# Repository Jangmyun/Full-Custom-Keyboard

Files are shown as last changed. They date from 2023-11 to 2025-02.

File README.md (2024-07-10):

# Full-Custom-Keyboard

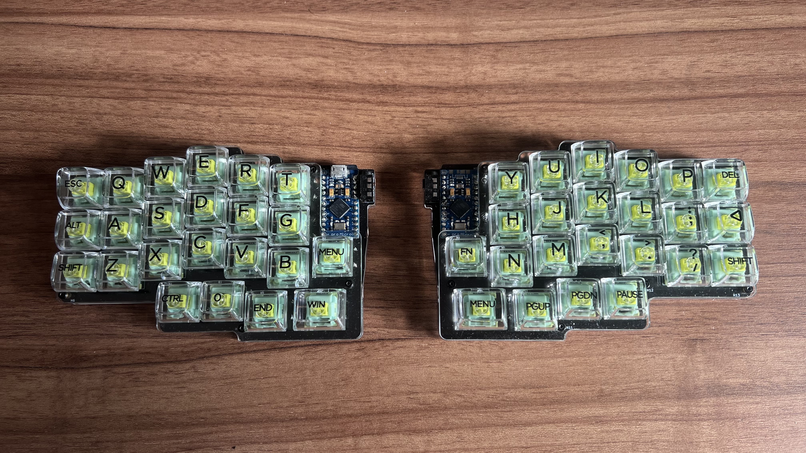
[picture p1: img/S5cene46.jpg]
s5cene


##### 목표: 아두이노 프로 마이크로 또는 rp2040-zero 보드를 사용하여 스플릿 키보드 제작

###### 저는 전자 비전공자이고, 전기 전자 아무것도 몰라도 무리없이 키보드 제작이 가능했습니다.<br>이 글은 구글링해서 얻은 자료들을 제작 순서에 맞게 짜깁기 한 내용에 불과합니다.

<br><br>

## 순서:

1. #### 레이아웃 설계

2. #### 회로도 설계

3. #### pcb 설계

4. #### 보강판, 상판 설계

5. #### pcb, 부품 주문

6. #### 납땜, qmk 펌웨어 플래시

7. #### 완성

<br><br>

1. ## 레이아웃 설계

#### 키보드 레이아웃 == 키보드 배열

##### 보통 키보드 레이아웃은 키보드 배열을 말하는데, 어떤 배열의 키보드를 만들지 정해야 회로도나 pcb를 설계할 때 고민할 일이 없으니 만들어 놓고 시작하는 것이 좋습니다.<br>키보드 레이아웃은 [keyboard-layout-editor](http://www.keyboard-layout-editor.com/) 에서 만들 수 있습니다.<br>GitHub 계정이 있다면 만든 레이아웃을 저장할 수도 있습니다. JSON 파일로 저장해도 됩니다.

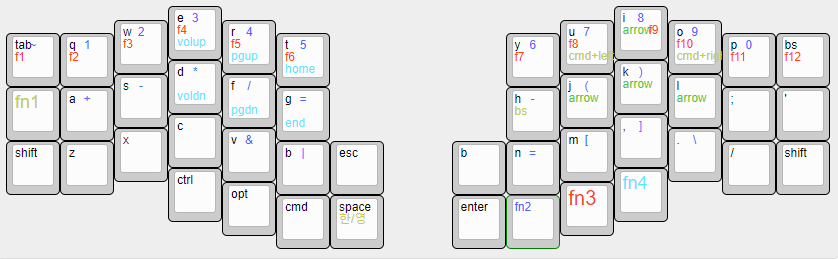
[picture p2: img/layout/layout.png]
layout


##### 저는 위 배열로 만들겠습니다. fn키를 누르면 나오는 키는 qmk 펌웨어를 사용해서 원하는 대로 어떤 것이든 지정할 수 있으니 나중에 편한대로 커스텀 해도 됩니다.

<br><br><br>

2. ## 회로도 설계

##### 회로도와 PCB는 [KiCad](https://www.kicad.org/) 라는 프로그램을 사용해서 설계할 것입니다. 버전은 7.0 이상의 stable 버전을 기준으로 설명하겠습니다.

<br>

### 회로도 설계전에 알아야 할 내용

#### [키보드 매트릭스 원리 이해하기](https://m.blog.naver.com/kdahaam/221495967863)에 잘 정리되어 있습니다.

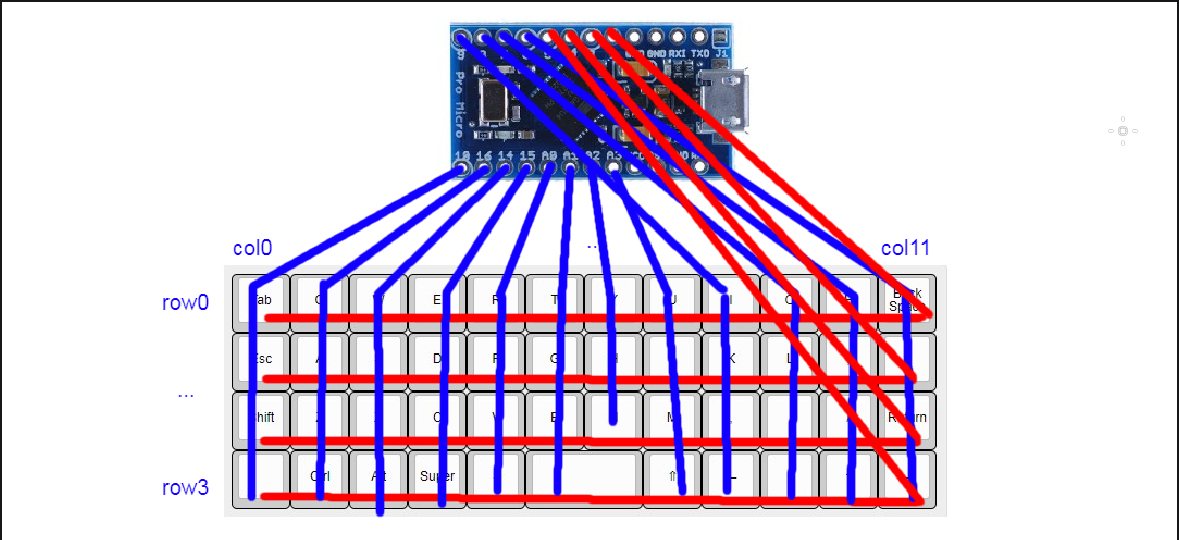
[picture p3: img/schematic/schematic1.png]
keyboard matrix


##### 

##### 적게는 40키, 많게는 100키가 넘어가는 키보드의 모든 스위치를 하나하나 컨트롤러에 연결하기에 컨트롤러의 핀 개수가 모자르게 됩니다. <br>때문에 행과 열로 스위치를 묶어서 연결하고 각 행과 열을 컨트롤러에 연결하면 훨씬 적은 핀으로 다수의 스위치를 인식할 수 있게 됩니다.<br><br>이렇게 되면 스위치를 하나만 눌렀을 때는 잘 작동하지만 여러 스위치를 동시에 눌렀을 때 눌리지 않은 키까지 인식하는 경우가 생깁니다. 이럴 때 사용하는 것이 `다이오드` 입니다. <br><br>다이오드는 전기를 한 방향으로만 흐르게 만드는 데, 이게 누르지 않은 스위치가 눌리는 현상을 막아줍니다. 잘 이해가 안된다면 `스위치 하나당 다이오드 하나가 필요하다` 정도로 생각하면 되겠습니다. 저는 46개의 스위치를 사용하기 때문에 다이오드 46개가 필요하겠네요.

<br><br>

### 회로도를 설계전에 필요한 파일 설치

#### KiCad를 실행합니다.

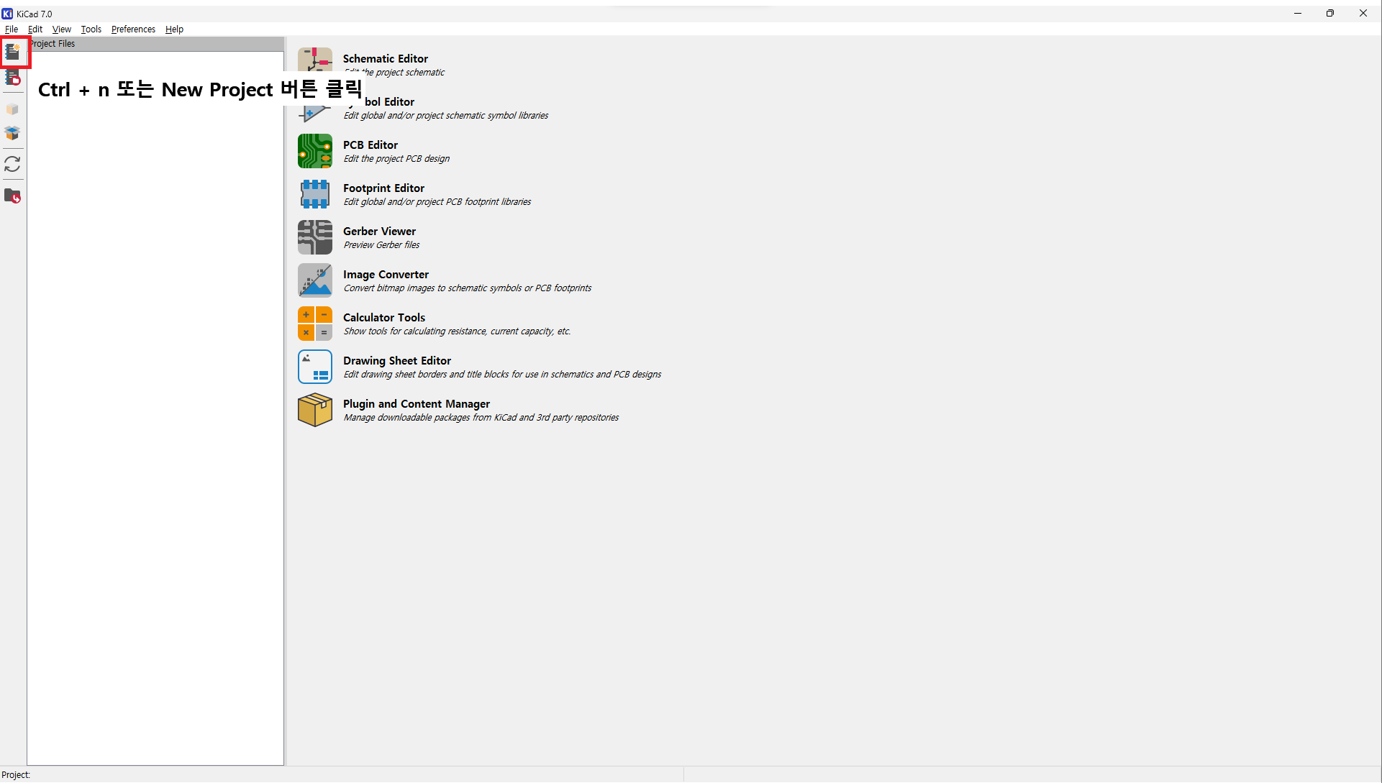
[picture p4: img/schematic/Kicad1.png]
Kicad1


##### `Ctrl + n` 또는 New Project를 눌러 새로운 프로젝트를 생성합니다. 프로젝트를 생성했을 때 `프로젝트이름.kicad_pcb`와 `프로젝트이름.kicad_sch`파일을 확인하면 됩니다.

#### Footprint와 Symbol 라이브러리 다운로드

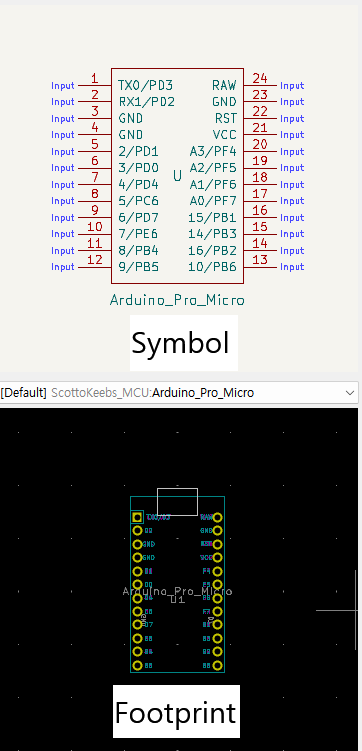
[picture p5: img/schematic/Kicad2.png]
Symbol and Footprint


##### Symbol은 우리가 키보드에 사용할 부품의 회로도 그림이고, Footprint는 pcb 설계할 때 사용할 부품의 실제 그림이라고 생각하면 되겠습니다.<br>우리가 사용할 부품을 잘 정리해놓은 [scottoKicad](https://github.com/joe-scotto/scottokeebs/tree/main/Extras/ScottoKicad)가 있습니다. [DownGit](https://minhaskamal.github.io/DownGit/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)사이트에서 바로 다운로드 할 수 있습니다.<br>라이브러리 적용 방법은 [KiCad 라이브러리 적용방법](https://github.com/Jangmyun/Full-Custom-Keyboard/tree/main/kicadLibrary)에 정리해두었습니다.

<br><br>

### 본격적으로 회로도를 그려봅시다.

##### 프로젝트 폴더를 열고 `kicad_sch`파일을 열어줍니다.

<p width="100%">
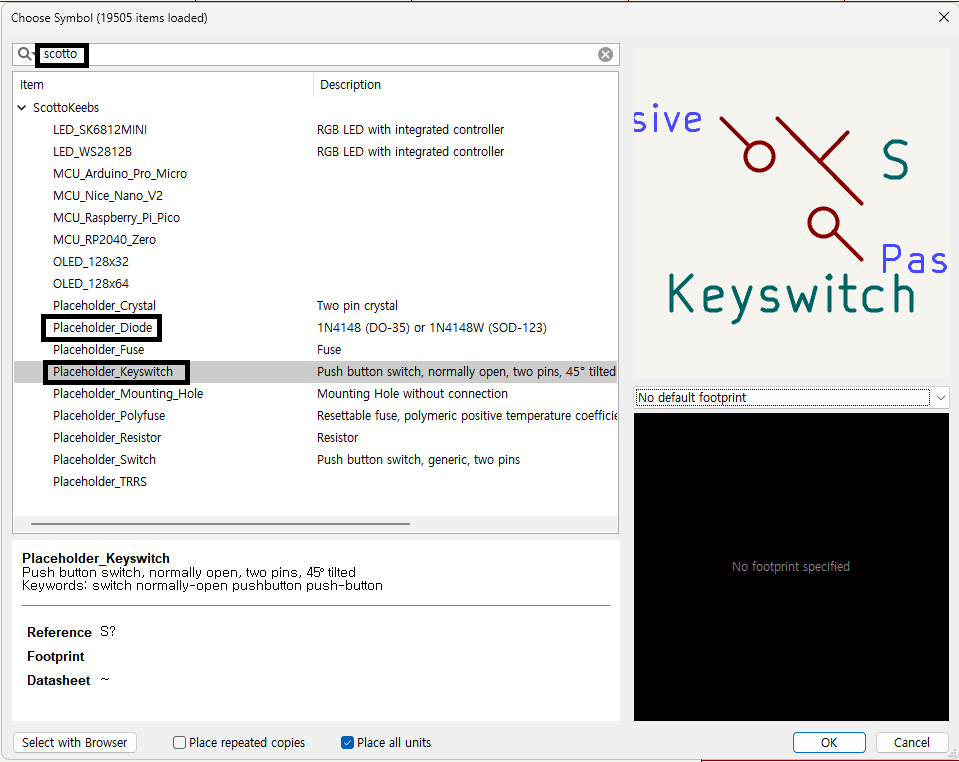
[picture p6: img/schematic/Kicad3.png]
  
</p>

##### 단축키 `A`를 눌러 스위치와 다이오드 심볼을 추가해주겠습니다. `scottokeebs`로 검색하면 앞서 적용한 심볼 라이브러리를 찾을 수 있습니다.

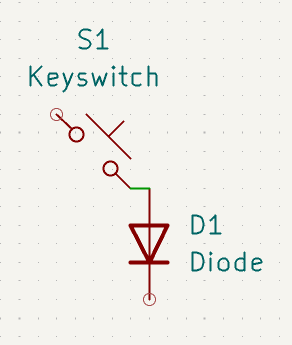
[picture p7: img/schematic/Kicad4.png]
keyswitch and diode


##### 추가한 스위치와 다이오드를 옮겨서 위와같이 만들어줍니다. 스위치와 다이오드 하나가 세트입니다.<br>이제 앞에서 만든 레이아웃대로 스위치와 다이오드를 배치하겠습니다.<br>스위치와 다이오드를 드래그하고 복사하면 됩니다. 일정한 간격으로 배치해야 와이어를 연결할 때 편리합니다.

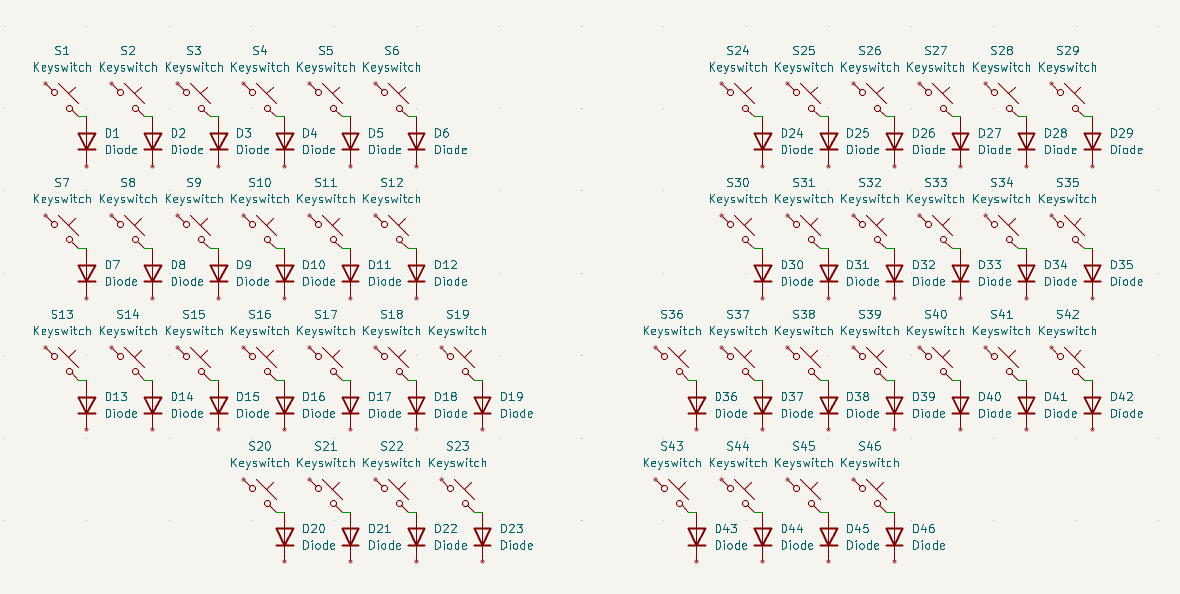
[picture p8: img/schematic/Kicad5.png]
schematic


##### 어지럽긴 하지만 이런식으로 배치가 됩니다. 저는 스플릿 키보드라서 좌,우 각각 떨어뜨려놨습니다.<br><br>이제 단축키 `W`로 각 행과 열을 연결해주겠습니다.

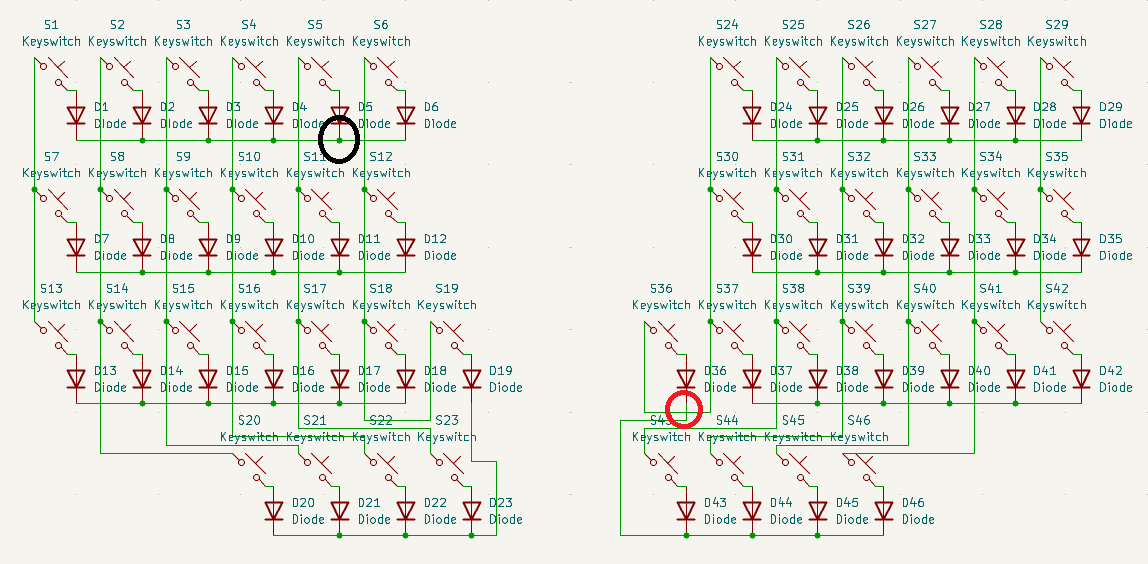
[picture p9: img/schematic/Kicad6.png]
schematic wiring


##### 이런 구조가 되는데, 연결할 때 검은색 원 안의 초록색 점은 서로 연결되었다는 뜻입니다. 연결되지 않은 선 끼리는 빨간색 원처럼 아무것도 표시되지 않습니다. 와이어 교차할 때 주의해야 합니다.

##### 다음은 각 행과 열에 라벨을 붙여줘야 합니다. 같은 이름의 라벨은 PCB 설계 단계에서 서로 연결됩니다.<br>`Ctrl + L`또는 회로도 편집기 우측의 `Global Label`을 선택하고 이름을 정해주면 됩니다.

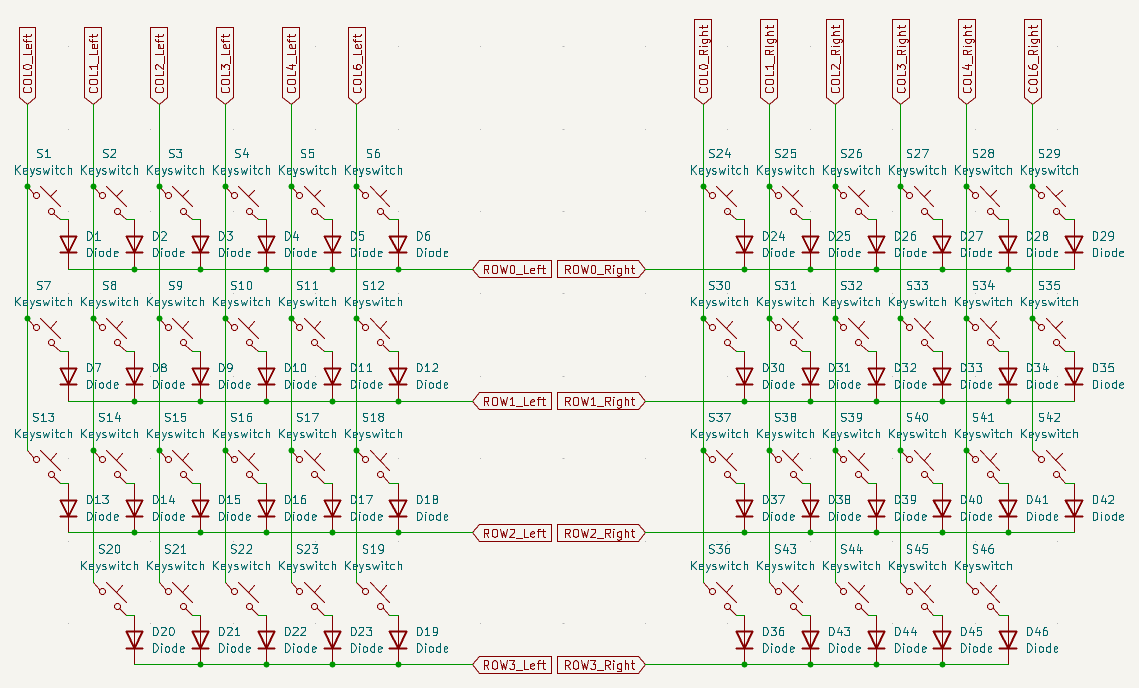
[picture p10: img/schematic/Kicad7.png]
Global Label


##### 라벨을 보기쉽게 만드려고 회로도를 조금 수정했습니다. 저는 스플릿 키보드를 만들거라 왼쪽 오른쪽의 라벨 이름을 구분해줬습니다. 보통 행열 라벨은 `col`과 `row`로 작명합니다.

##### 이제 MCU를 회로도에 추가합니다. 스플릿 키보드라서 두개 추가해줍니다. 저는 rp2040-zero를 사용하겠습니다. 단축키 `A`를 누르고 rp2040-zero를 추가합니다.

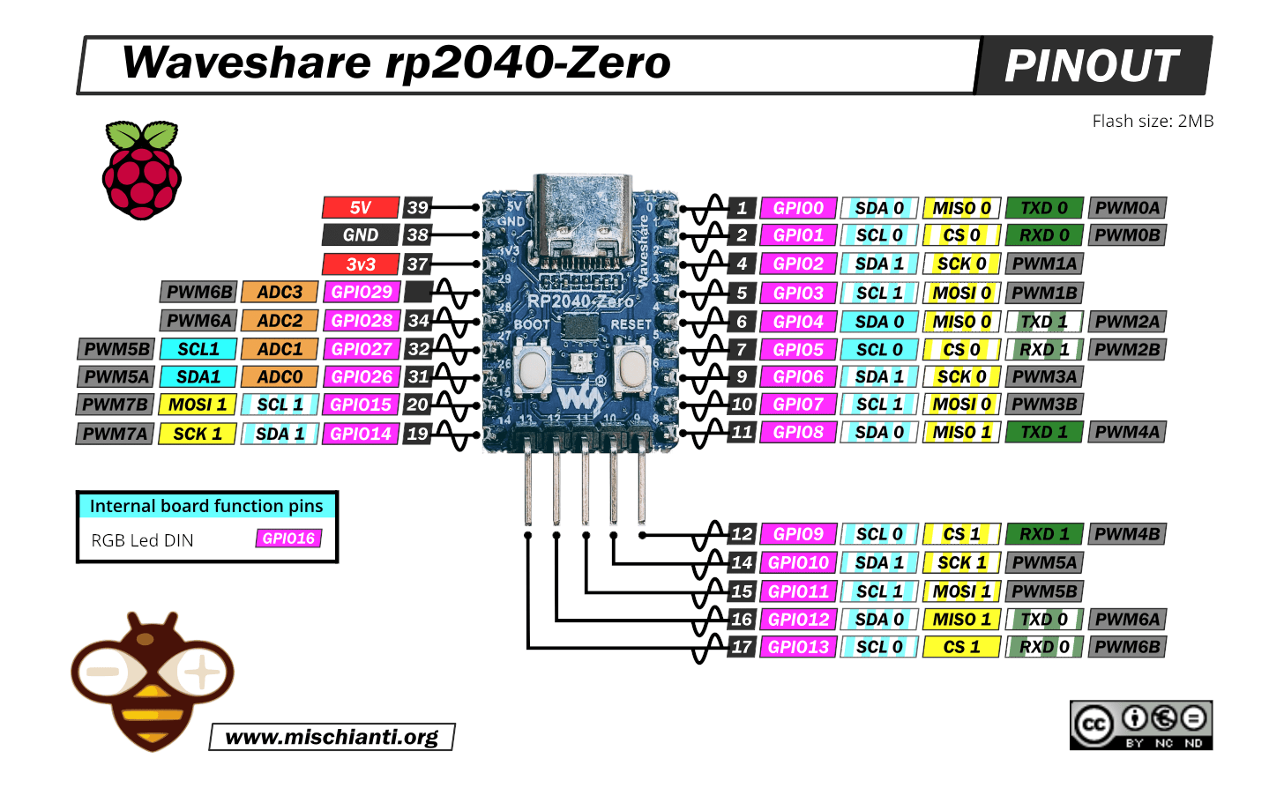
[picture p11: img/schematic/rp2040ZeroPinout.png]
rp2040-zero-pinout (https://mischianti.org/waveshare-rp2040-zero-high-resolution-pinout-and-specs/)


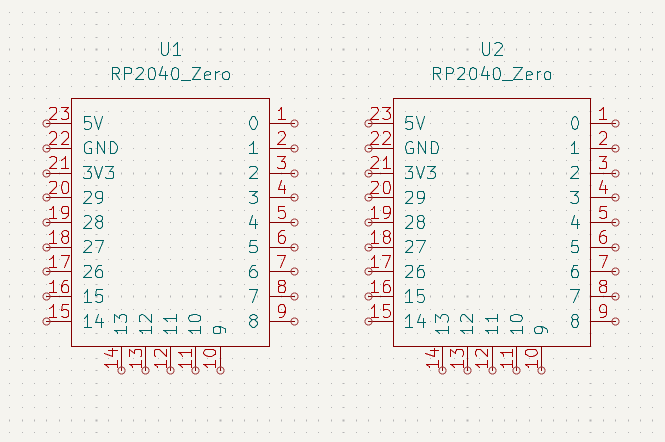
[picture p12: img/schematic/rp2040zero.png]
rp2040-zero


##### 총 23개의 핀이 있는데 그중에서 `3V3`,`GND`,`5V`외에는 자유롭게 행열을 연결할 수 있습니다. 다만 스플릿 키보드를 만들 때는 좌우 컨트롤러의 시리얼 통신을 위해 `GPIO0`, `GPIO1` 핀을 비워주겠습니다.

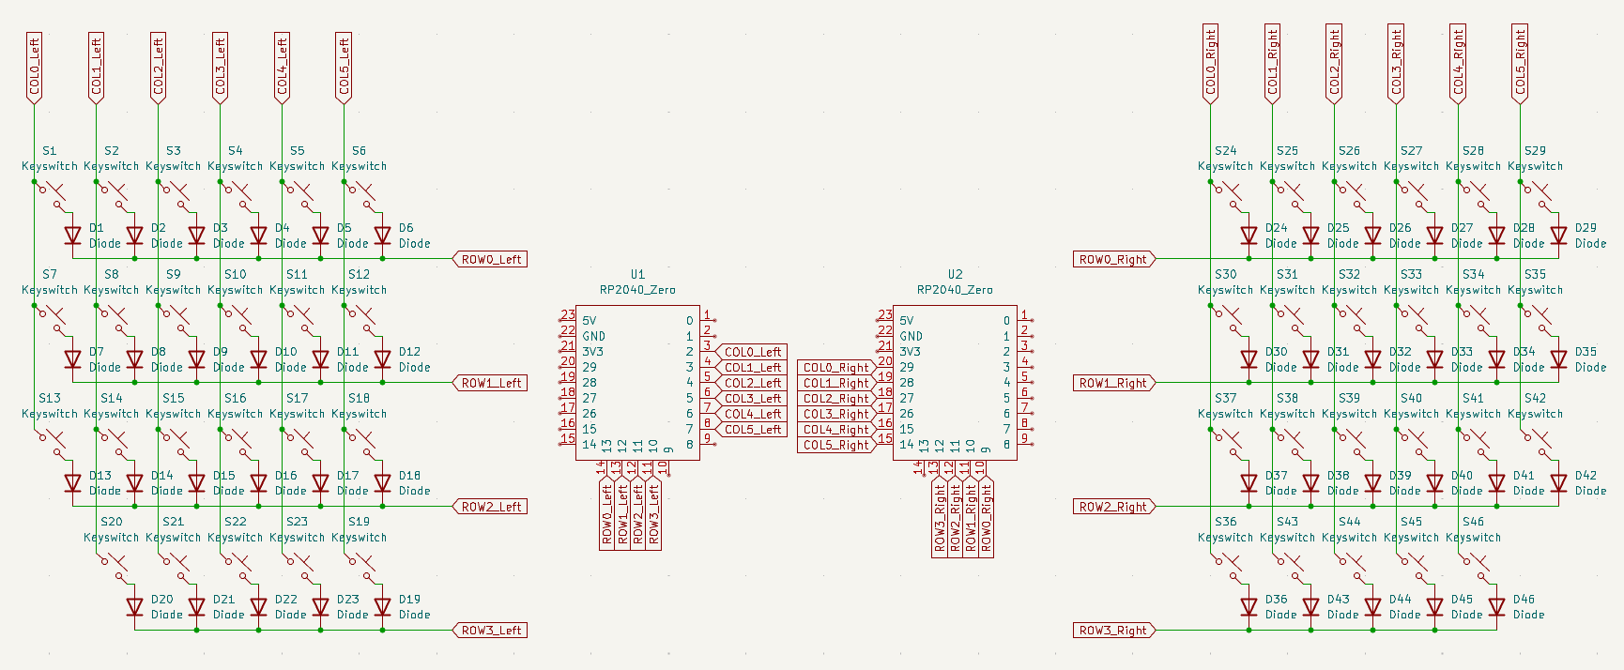
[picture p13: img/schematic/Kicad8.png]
keyboard matrix connection


##### 연결을 완료했습니다. PCB 설계과정에서 다시 돌아와 수정할 수 있으니 연결되는 위치는 크게 중요하지 않습니다.

### [좌우 컨트롤러의 통신 방법 (스플릿 키보드만 해당)](https://docs.qmk.fm/#/serial_driver?id=usart-full-duplex)

##### MCU의 통신방법은 여러가지가 있는데 우리는 시리얼 통신, 그중에서도 `USART Full-Duplex` 방식을 사용하겠습니다. 이름부터 어려워보이는데 그냥 선 네 개만 잘 연결하면 됩니다.<br>좌우의 연결은 3.5mm 이어폰 잭 (TRRS)로 할겁니다. 따라서 TRRS 커넥터를 추가하겠습니다. `Placeholder_TRRS`로 검색해서 두 개 추가해줍니다.

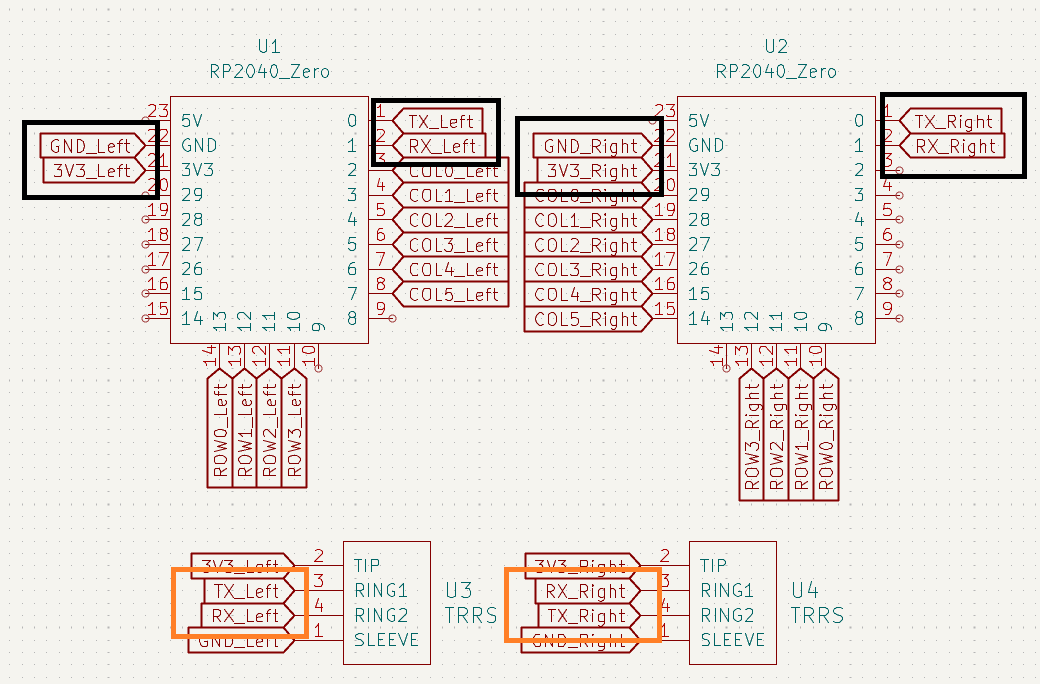
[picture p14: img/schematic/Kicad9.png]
trrs connection


##### USART Full-Duplex 방식은 TX를 RX에, RX를 TX에 연결해야 합니다. 저는 간단히 TRRS 커넥터의 TX와 RX를 좌우가 엇갈리도록 하겠습니다. 빨간 박스처럼 하면 됩니다.

##### 이제 회로도는 완성됐습니다. PCB파일로 넘어가기 전에 회로도에 들어간 부품들의 실제 Footprint를 지정해줘야 합니다.

footprint assignment tool

##### 에디터 상단의 Footprint Assignment Tool을 열어줍니다.

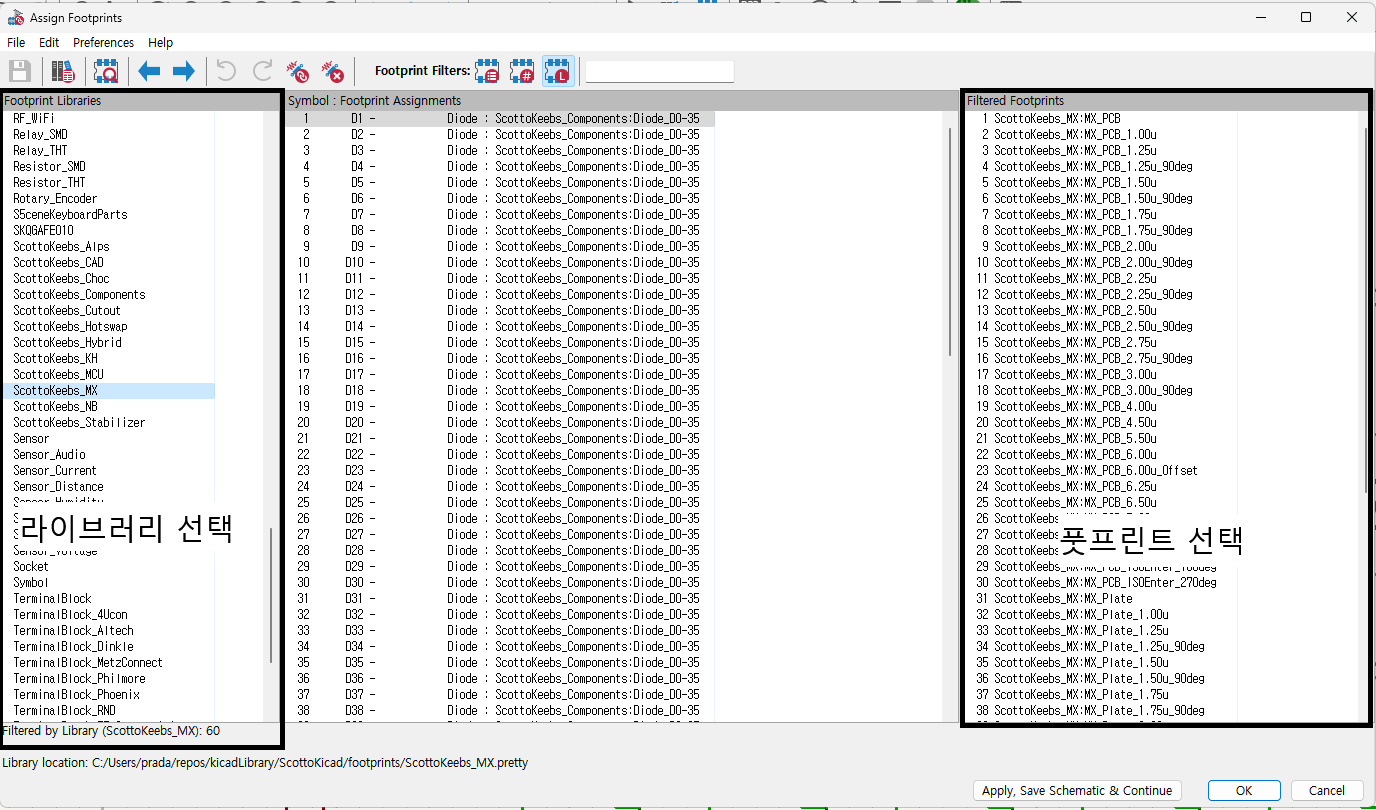
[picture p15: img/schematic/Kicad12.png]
footprint assignment


##### 같은 종류의 부품을 `shift + 마우스클릭`으로 선택해주고 라이브러리에서 부품에 맞는 풋프린트를 더블클릭해주면 적용됩니다.<br>각 심볼에 맞는 풋프린트의 라이브러리와 이름은 다음과 같습니다.

| 심볼 | 라이브러리 | 풋프린트 이름 |
| --- | --- | --- |
| Diode | ScottoKeebs_Components | Diode_D0-35  |
| Keyswitch | ScottoKeebs_MX | MX_PCB_1.00u |
| RP2040_Zero | ScottoKeebs_MCU | RP2040_Zero  |
| TRRS | ScottoKeebs_Components | TRRS_PJ-320A |

##### 만약 다른 사이즈의 키캡을 사용한다면 각 사이즈에 맞는 MX스위치 풋프린트를 사용하면 됩니다. 여기까지 하면 회로도는 완성입니다. 이제 PCB 디자인으로 넘어가겠습니다.

<br><br>

3. ## PCB 설계

pcb editor open

##### 열려있는 회로도 에디터에서 PCB 에디터를 바로 열어줍니다.

<p width="100%">
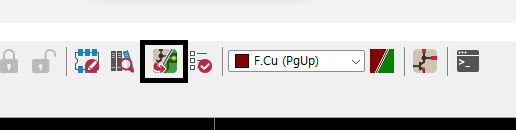
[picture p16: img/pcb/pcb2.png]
  
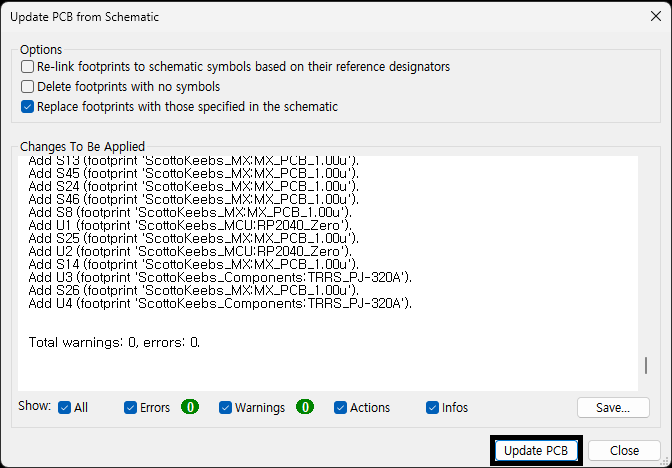
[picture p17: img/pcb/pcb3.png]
  
</p>

##### 회로도 에디터의 수정사항들을 PCB에 반영합니다.

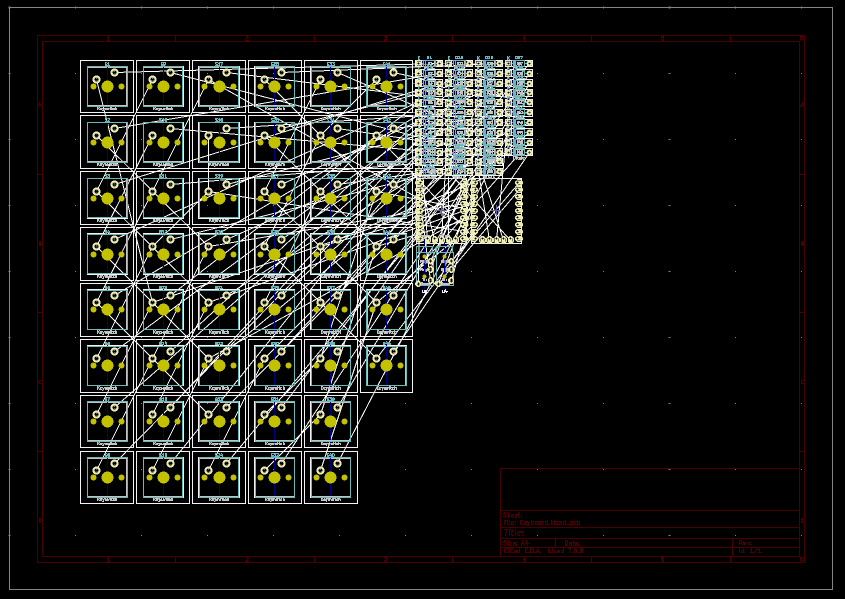
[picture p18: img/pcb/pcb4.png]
pcb updated


##### 이제 어지럽게 얽힌 풋프린트들이 에디터에 생깁니다. 서로 연결된 선끼리 이어주면 됩니다. 그 전에 만들고자 하는 키보드의 레이아웃에 맞게 스위치와 다이오드를 정렬해줘야 합니다.

##### 스위치 하나의 가로세로 길이는 `19.05mm`입니다. pcb에디터의 격자 사이즈를 19.05mm를 4로 나눈 `4.7625mm`로 설정하고 진행하겠습니다.

<p width="100%">
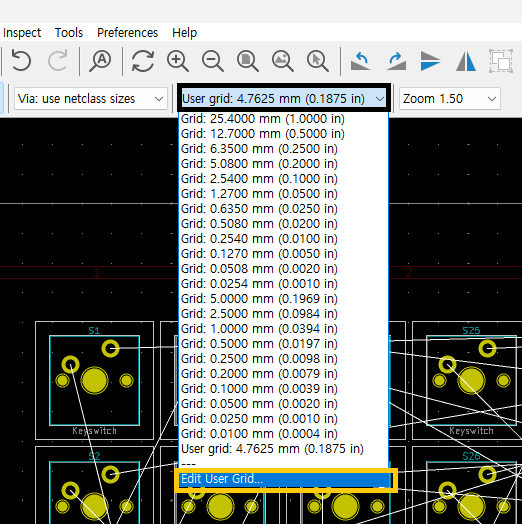
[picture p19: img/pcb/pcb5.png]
  
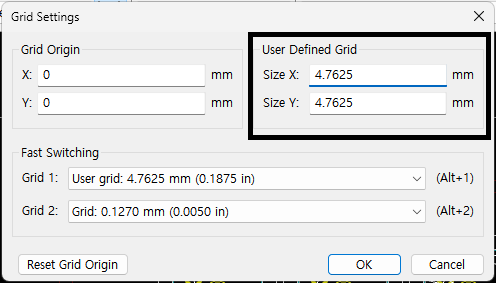
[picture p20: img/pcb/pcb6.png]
  
</p>

##### User Grid에서 `4.7625mm`로 그리드를 설정해줍니다. 이제 모든 스위치를 예쁘게 정렬하면 됩니다.

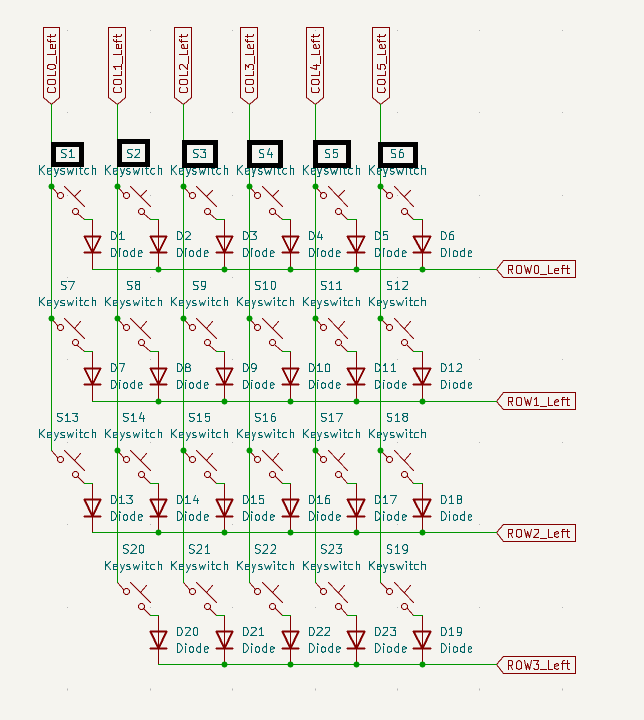
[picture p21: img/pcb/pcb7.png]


##### 기존의 스위치 번호에 유의해서 배치해주면 됩니다. 위치를 중구난방으로 해도 되기는 하는데 나중에 지옥이 펼쳐지니 순서대로 해주세요.

#### 꿀팁:

<p width="100%">
  
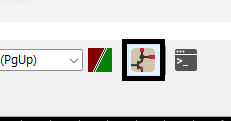
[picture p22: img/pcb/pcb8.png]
  
</p>

##### 회로도, pcb에디터 각각 상단의 버튼을 눌러 왔다갔다 할 수 있습니다.<br>이게 왜 좋냐면 회로도 에디터에서 심볼을 선택하면 PCB 에디터에서도 선택된 상태가 됩니다. <br>또 스위치 정렬이 잘 안될 때가 있는데 스위치를 드래그할 때 스위치의 중심부를 잡고 이동하셔야 스위치간 간격이 정확히 맞습니다.

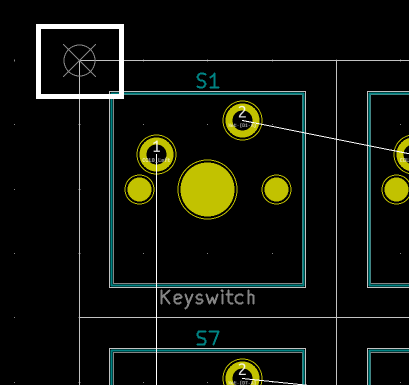
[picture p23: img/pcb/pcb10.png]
gride reference


##### 단축키 `S`를 눌러 가장 좌측 상단의 스위치의 좌상단 꼭짓점을 격자의 기준으로 지정합니다.

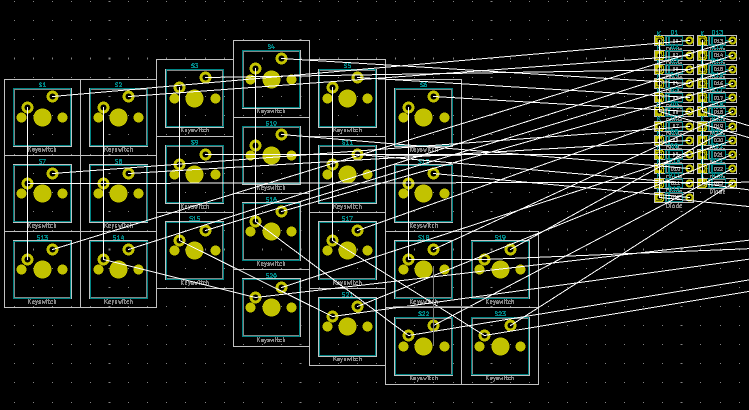
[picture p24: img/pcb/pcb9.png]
switch align complete


##### 스위치 정렬이 끝났습니다. 이제 다이오드를 스위치 사이에 끼워넣기 하겠습니다.

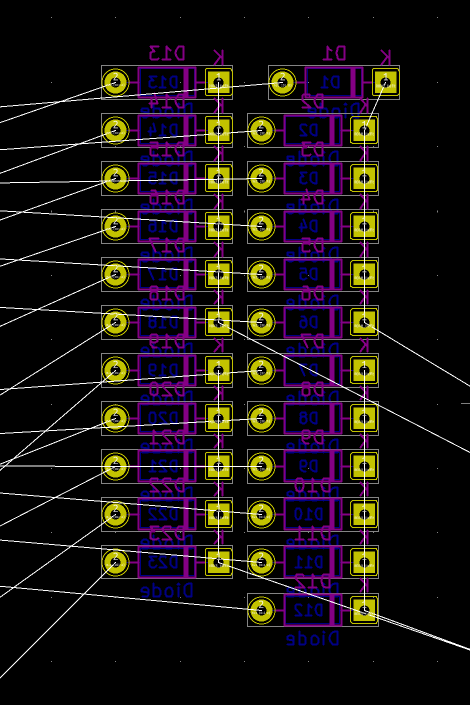
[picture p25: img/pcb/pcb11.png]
flip diodes


##### 다이오드는 PCB 기판의 하단에 넣을겁니다. 다이오드를 전부 선택하고 단축키 `F`를 눌러 뒤집어줍니다. 이제 스위치 사이사이에 다이오드를 배치해줍니다.

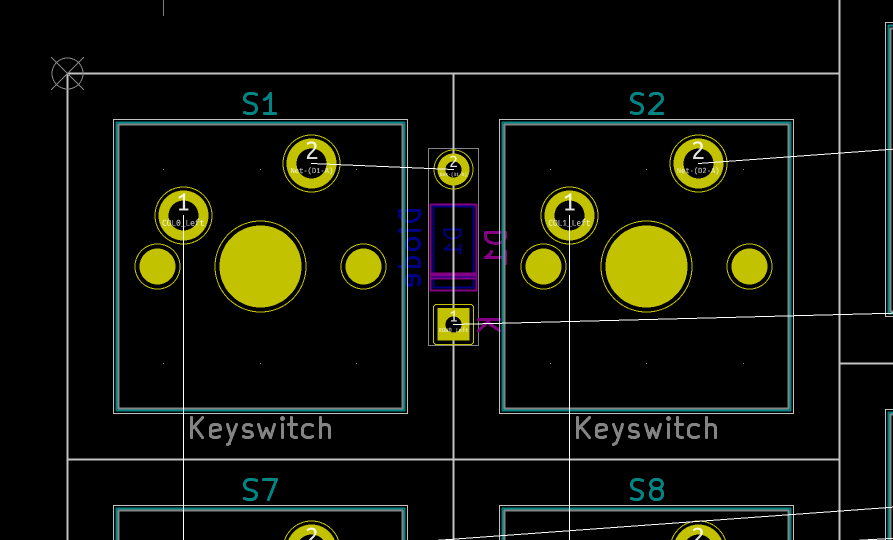
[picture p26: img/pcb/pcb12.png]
diode position


##### 스위치의 1/4 지점에 배치해줍니다. 개인적으로 이렇게 배치하는게 행열 연결할 때 깔끔하게 할 수 있어서 좋았습니다.

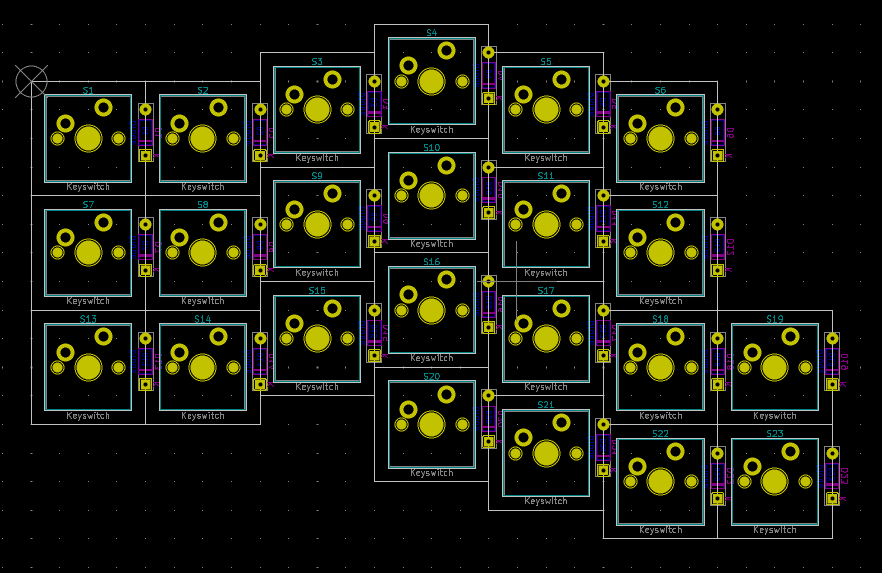
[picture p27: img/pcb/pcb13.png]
diode positioning complete


##### 다이오드 정렬이 끝났습니다. 이제 rp2040-zero와 trrs 커넥터를 배치하고 회로도에 맞춰 선을 연결해주겠습니다.<br>단축키 `X`키로 배선을 시작할 수 있습니다.<br>배선작업을 하기 전에 미리 볼트가 들어갈 구멍을 뚫고 시작해도 됩니다.

#### [KiCAD 사용법 강좌-배선/Copper/비아뚫기 - YouTube](https://youtu.be/5w91CukhzNU?si=pJJ6Ocjb_U-1WQmc)

##### 위 영상에서는 배선 굵기를 조절하는데, 우리는 스위치가 눌린 것만 인식하면 되는 키보드라 따로 조절할 필요는 없습니다. `F.Cu`와 `B.Cu`를 단축키 `V`로 바꿔가면서 배선을 할 수 있습니다.

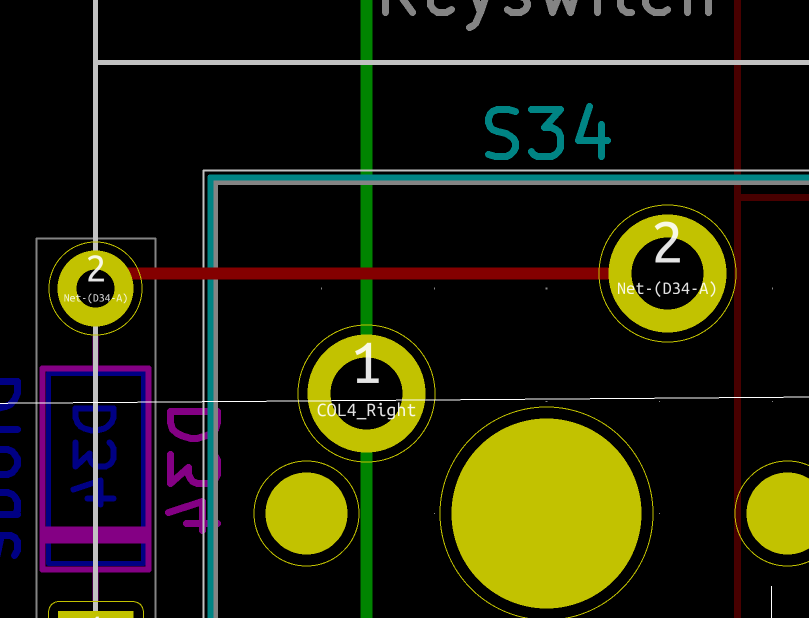
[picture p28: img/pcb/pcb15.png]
routing


##### 빨간색이 `F.Cu`고 초록색이 `B.Cu`입니다. 두 선은 각각 앞면, 뒷면의 배선이기 때문에 겹쳐도 합선되지 않습니다. 적절히 섞어가면서 배선작업을 해주면 됩니다.

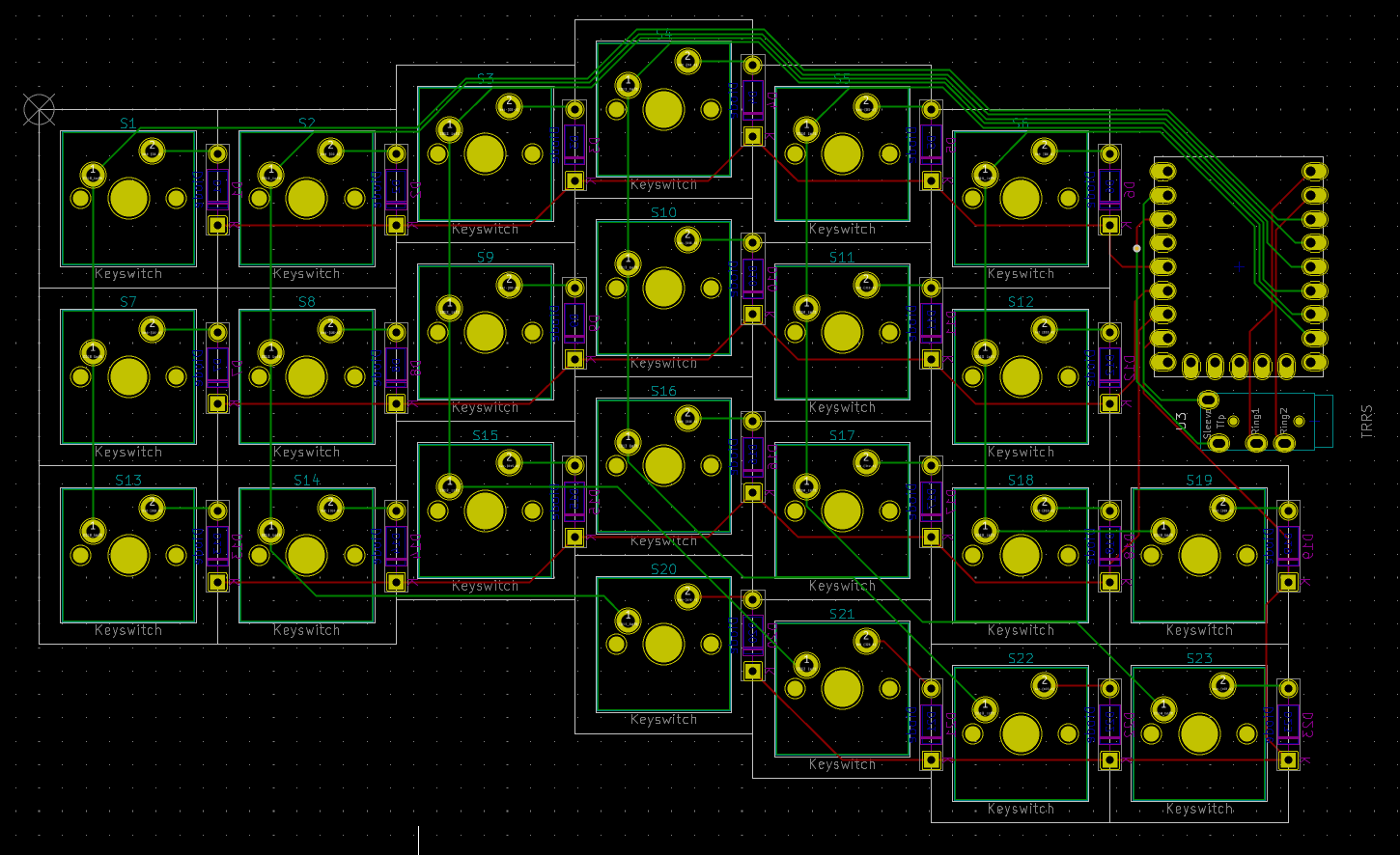
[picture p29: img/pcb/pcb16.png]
routing complete


##### 배선이 완료되었습니다. 저는 여기서 기판을 고정할 볼트가 들어갈 구멍을 뚫어주겠습니다. 다시 회로도 에디터로 돌아갑니다.

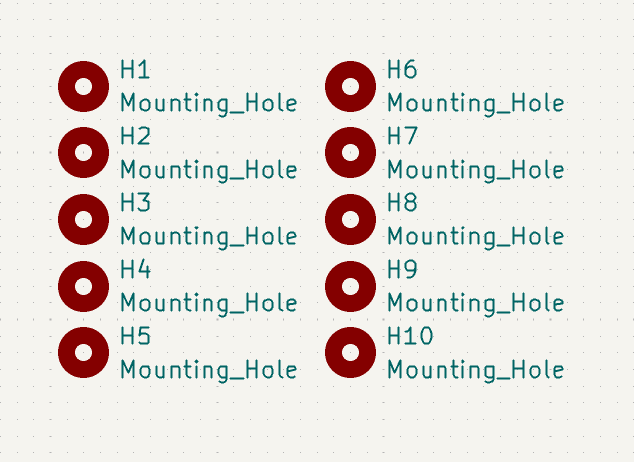
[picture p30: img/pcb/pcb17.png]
Mounting Hole


##### `Placeeholder_Mounting_Hole`로 검색하고 추가해줍니다.<br>Footprint Assignment Tool을 열어 `MountingHole` 라이브러리의 `MountingHole_2.2mm_M2`를 선택해줍니다. M2 사이즈의 볼트를 사용할겁니다.

##### 다시 PCB 에디터로 돌아와 회로도의 변경사항을 업데이트해줍니다.

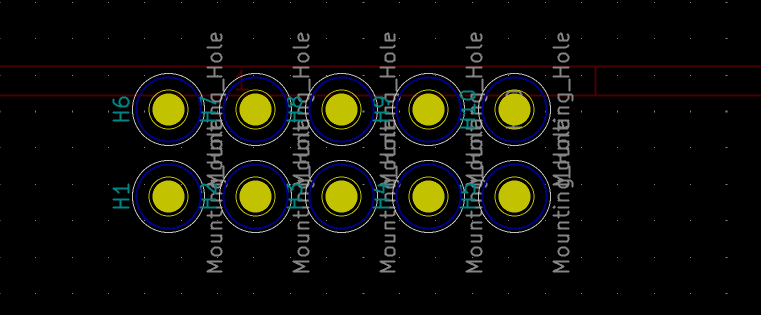
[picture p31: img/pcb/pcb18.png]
Mounting hole added


##### 나사 체결 홀이 생겼습니다. 이제 이걸 적절한 위치에 배치해주겠습니다.

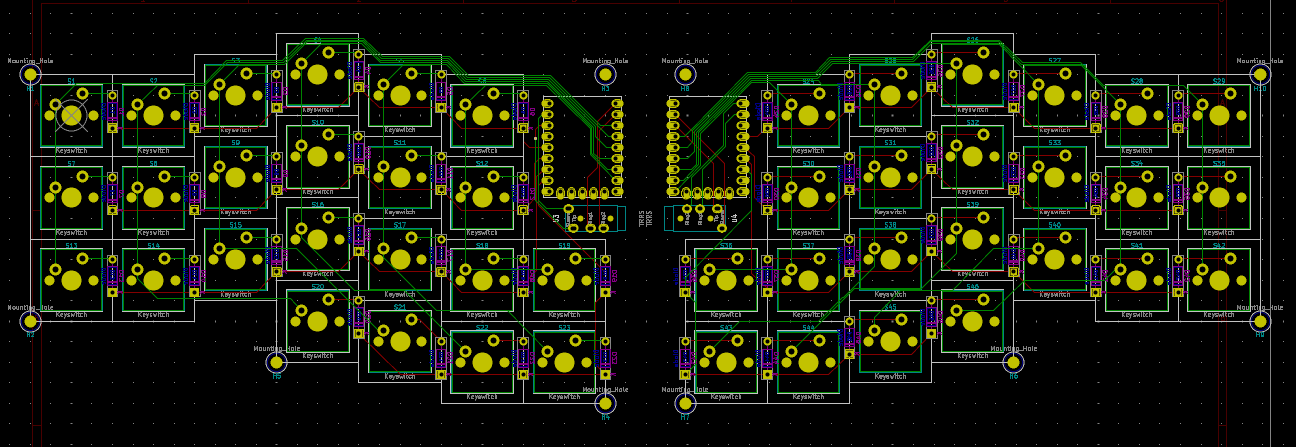
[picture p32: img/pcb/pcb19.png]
mountinghole align


##### 배치가 완료됐습니다.

#### 이제 기판의 가장자리 커팅라인을 그려줘야 합니다.

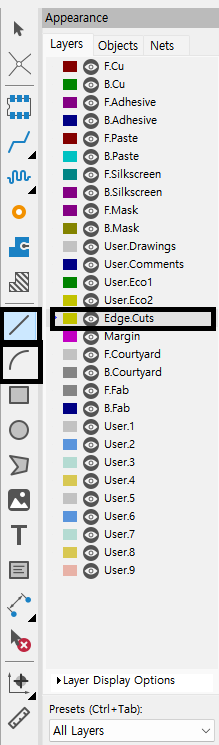
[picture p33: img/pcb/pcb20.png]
edge cut


##### `Edge.Cuts`를 선택해주고 직선과 호를 그려 PCB의 모양을 잡아주겠습니다.

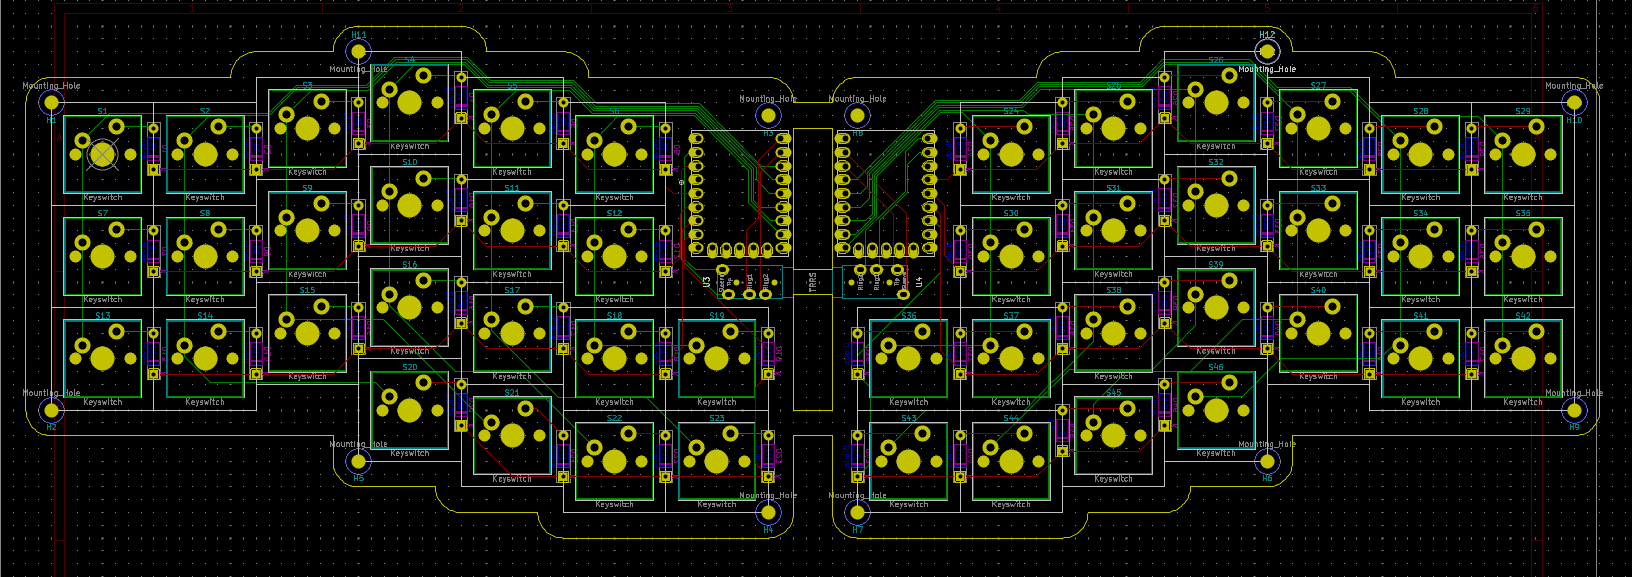
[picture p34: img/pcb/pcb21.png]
edge cuts


##### 이런 모양이 됩니다. 왼쪽 오른쪽 따로 만들어도 되는데 주문시 가격이 더 올라가기 때문에 통째로 만들어서 잘라서 사용하는 방식으로 하겠습니다.

#### Design Rules Checker로 잘못된 부분이 있는지 확인해보겠습니다.

DRC

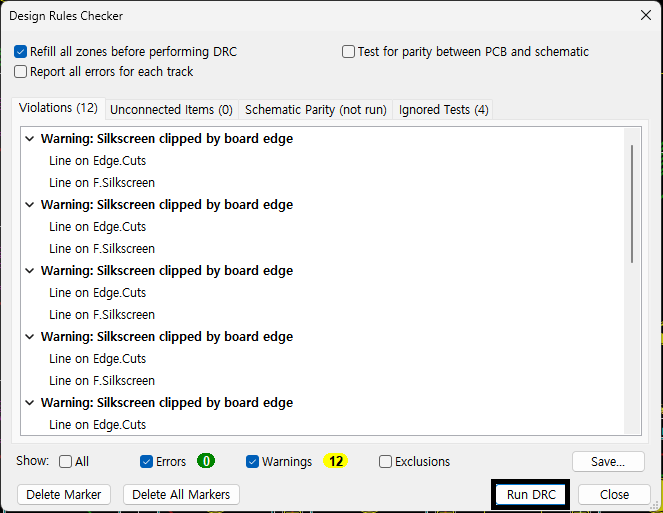
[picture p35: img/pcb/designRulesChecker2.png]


##### `Run DRC`버튼을 눌러 확인합니다. `Warnings`에 12개가 나오지만 일단 `Errors`를 중점적으로 체크해주면 됩니다.

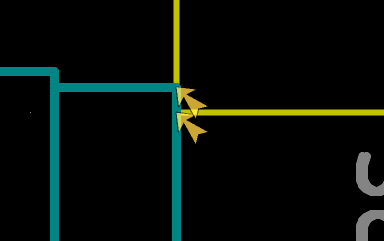
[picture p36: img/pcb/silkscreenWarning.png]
silkscreen warning


##### `Warning`은 대부분 실크스크린(PCB위에 실제로 그려지는 부분)이 잘리면서 생기는 것이 대부분입니다. 크게 신경쓰지 않아도 작동에 이상이 없습니다.

#### 이제 PCB의 나머지 부분을 구리로 채워주겠습니다.

<p width="100%">
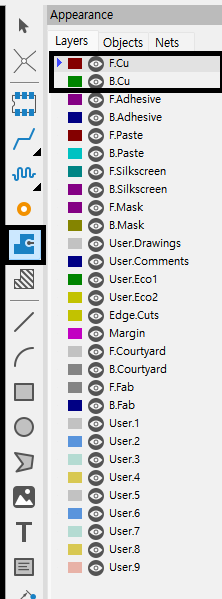
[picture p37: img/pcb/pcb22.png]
  
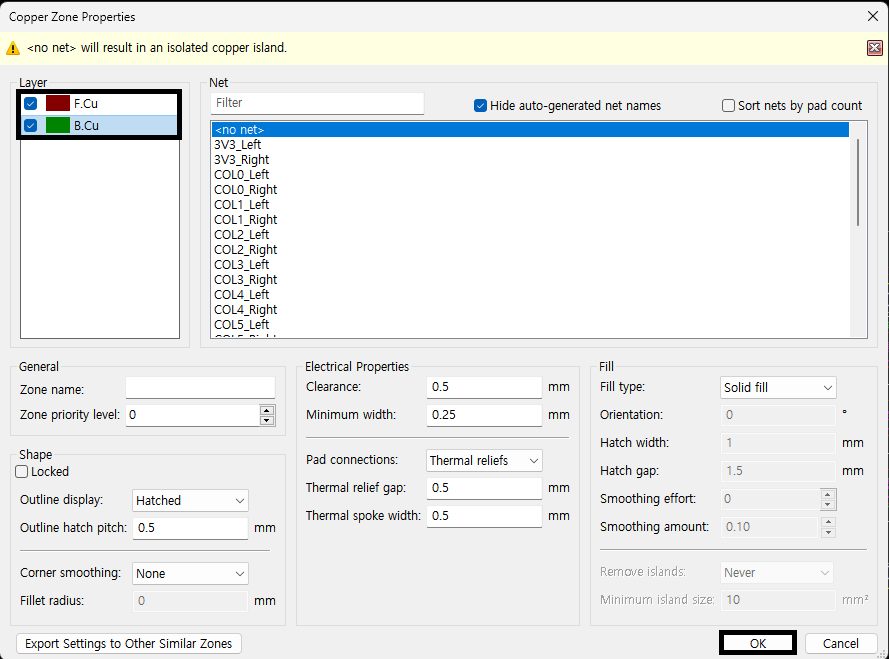
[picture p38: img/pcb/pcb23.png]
  
</p>

##### 단축키`Ctrl + Shift + Z`나 `Add filled Zone` 버튼을 누르고 에디터의 빈 공간을 클릭해줍니다.<br>레이어를 두개 다 체크 해주고 OK버튼을 누릅니다.

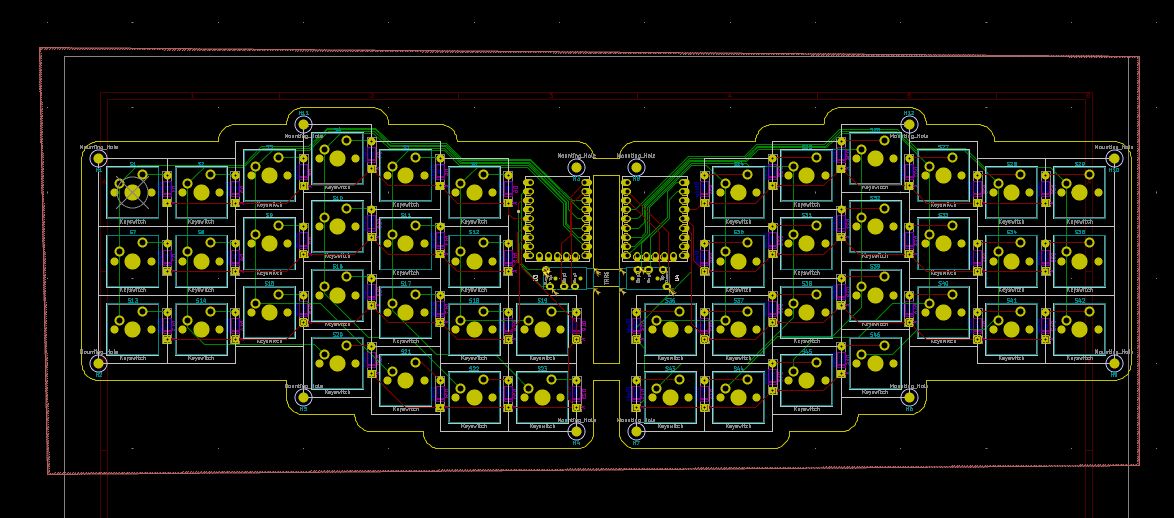
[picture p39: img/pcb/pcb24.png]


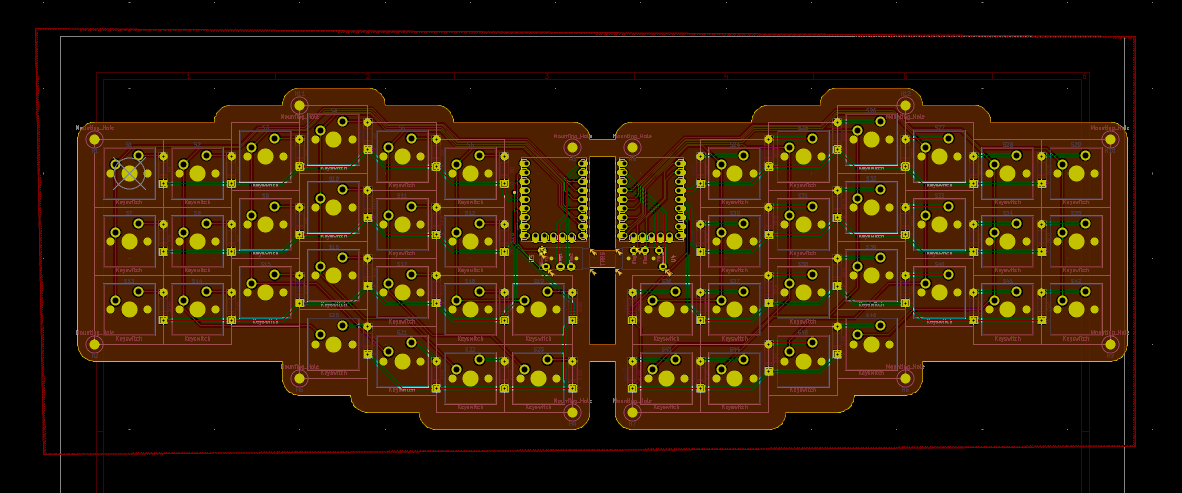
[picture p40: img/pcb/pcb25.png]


##### PCB 전체를 감싸주고 단축키 `B`키를 눌러 채워줍니다.<br>PCB 디자인의 모든 과정이 끝났습니다. 이제 이 파일을 거버 `.gbr` 파일로 저장해야합니다.

#### [How to generate Gerber and Drill files in KiCad 7](https://jlcpcb.com/help/article/362-how-to-generate-gerber-and-drill-files-in-kicad-7)

##### 위 링크는 우리가 PCB를 주문할 업체인 JLCPCB의 설명문입니다. 그대로 따라해서 거버파일을 한 폴더에 저장하면 됩니다.

###### 수정사항:

fix

###### pcb의 전체적인 디자인과 홀 위치를 수정했습니다.

<br><br>

4. ## 보강판, 하판 설계

##### 이제 보강판, 하판 설계를 해야합니다. 저는 Fusion360 무료버전을 사용해서 만들었습니다.<br>이 부분은 설명하기가 너무 어려워서 잘 만들어진 유튜브 강좌로 대체하겠습니다.<br>진짜 너무 어려워서 설계하기가 힘들다 하시는 분들은 스위치를 고를 때 5핀 스위치를 선택하시고 하판은 최소구매 수량때문에 남는 PCB를 하판으로 이용하면 됩니다. <br>근데 이러면 키보드가 정말 기괴해지니까 저는 보강판을 설계하겠습니다.

[메이커를 위한 Fusion 360 모델링 - YouTube](https://youtube.com/playlist?list=PLovJKdHnVxzlUSWneVlyuwuWpvtWabgab&si=KHW3WNaJRUbpsRhU)

##### 약 2시간 반 정도 강의 따라가면 `.dxf` 형식의 평면 도면 정도는 쉽게 만들 수 있습니다.

<p width="100%">
  
</p>

##### mx 스위치 상판에는 스위치를 끼울 구멍을 내야하는데, `14mm`로 만들면 됩니다. 저도 아직 툴 사용이 미숙해서 Fusion360 단축키 `D`를 사용해서 길이 노가다를 해줬습니다.

[CherryMX.pdf - Google Drive](https://drive.google.com/file/d/1mCyr-2AKkUAvFVv7urUcg1ZXiUHRZjrM/view)

##### 위 링크는 체리MX 스위치의 상세 스펙입니다. 인치로 표기되어있습니다..

<p width="100%">
  
  
</p>

##### 보강판과 하판을 만들어주었습니다. 일단 보강판을 만들면 하판은 거기서 조금만 수정하면 됩니다.

<p width="100%">
  
</p>

##### 실제로 체결하게 되면 이렇게 됩니다.

[How to save or export a Sketch as DXF in Fusion 360](https://www.autodesk.com/support/technical/article/caas/sfdcarticles/sfdcarticles/How-to-Save-Sketch-as-DXF-in-Fusion-360.html)

##### 만든 도면을 DXF 파일로 저장해줍니다.

<br><br>

5. ## PCB, 부품 주문

##### 이제 PCB와 보강판 설계가 완료됐으니 주문을 해야합니다.

#### PCB:

##### PCB의 경우 [JLCPCB](https://jlcpcb.com/)에서 주문할 수 있습니다.

order

##### 사이트 회원가입/로그인 후 `Order now`를 누르고 미리 만들어둔 Gerber 파일이 든 폴더를 zip파일로 압축해서 업로드합니다.

order1

##### 파일이 정상이라면 다음처럼 Gerber viewer가 표시됩니다.<br>주문서 아래를 보면 옵션이 매우매우 많은데 우리가 볼 것은 `PCB Color`와 `Surface Finish`뿐입니다. PCB의 색깔은 개인취향에 따라 선택하면 되고 표면마감의 경우 `HASL`과 `ENIG` 방식이 있습니다. 간단히 말하면 `HASL`가 더 싸고, `ENIG`가 마감은 더 좋지만 비쌉니다. 저는 저렴한 HASL로 결정했습니다.<br>결제는 해외결제 카드나 페이팔을 이용하면 됩니다. 아마 처음 회원가입 시 주는 쿠폰이 있을텐데 최대한 이용하는 걸 추천합니다.

##### <br>

#### 보강판:

##### 보강판, 하판은 아크릴로 만들건데, [아트릴](http://www.artryl.com/)이라는 곳을 이용하겠습니다.<br>`제작문의 > 글쓰기`에서 만든 DXF파일을 업로드해주고 원하는 아크릴 색상과 두께를 적어주면 됩니다.<br>저는 상판, 하판 모두 `2t (2mm)`로 했습니다.

<br>

#### 나머지 부품들:

##### [rp2040-zero](https://ko.aliexpress.com/item/1005004281549886.html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)

##### [Male-Female/M2x3 & Female-Female/M2x3](https://ko.aliexpress.com/item/1005004564012666.html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)

##### [M2/4mm](https://ko.aliexpress.com/item/1005005070119421.html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)

<br>

##### 제작에 필요한 부품을 모두 구매했습니다. 이제 도착할 때까지 기다리면 됩니다..

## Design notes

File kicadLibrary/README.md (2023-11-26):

# KiCad 라이브러리 적용 방법

##### 파일을 다운받았다면 압축을 풀어줍니다.

<figure class="half">
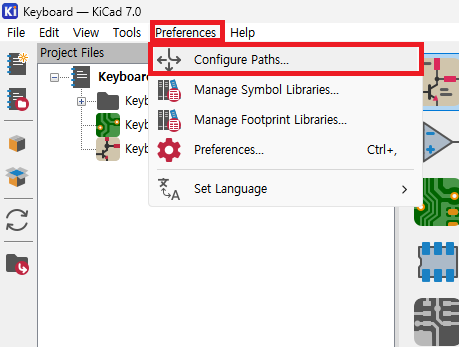
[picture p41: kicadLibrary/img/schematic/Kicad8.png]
    
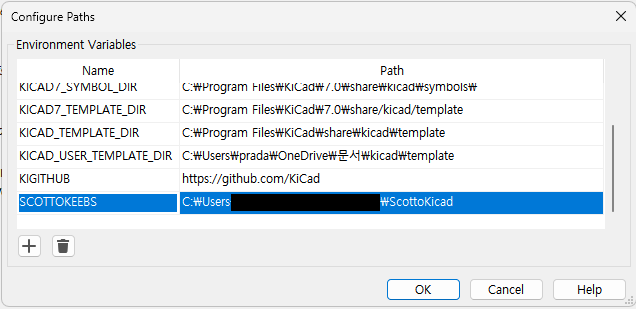
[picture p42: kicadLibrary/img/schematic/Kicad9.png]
    
</figure>

##### `Preferences > Configure Paths` 로 들어가서 압축을 푼 파일을 선택해줍니다. 이름은 아무렇게나 지어도 됩니다.

<figure class="half">
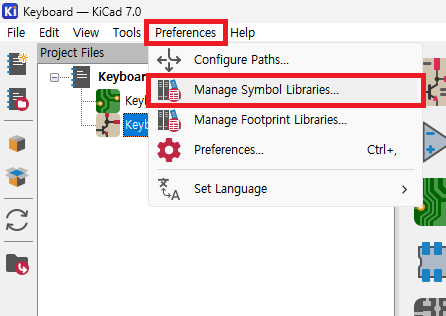
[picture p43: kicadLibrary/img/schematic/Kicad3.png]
    
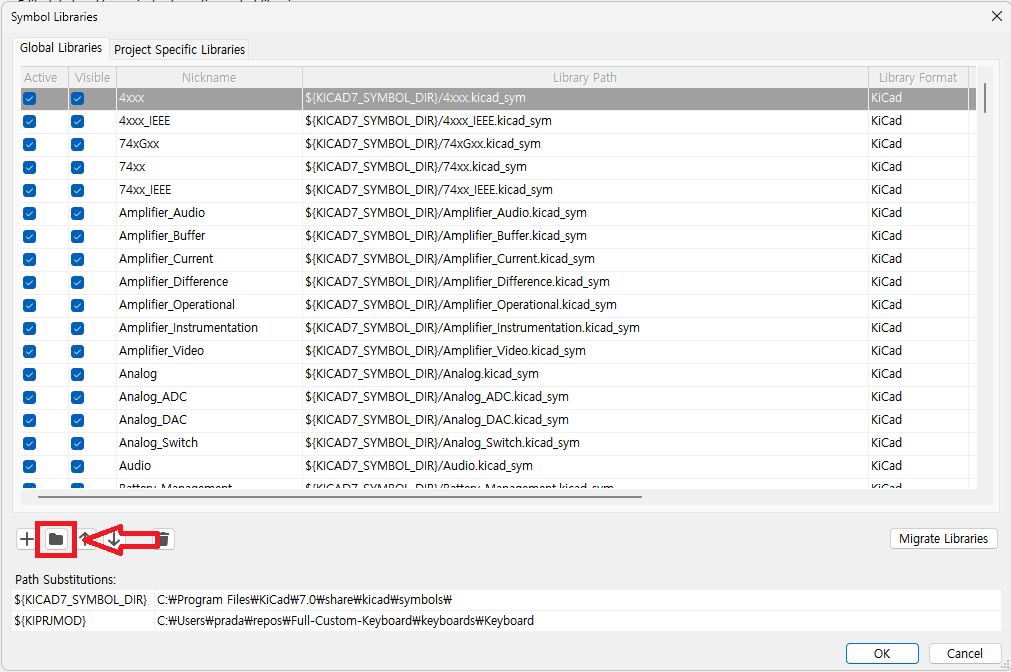
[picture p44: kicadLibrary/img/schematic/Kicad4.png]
    
</figure>

##### `Preferences > Manage Symbol Libraries` 로 들어가서 압축을 푼 파일 내부의 `.kicad_sym` 확장자를 선택하고 추가해줍니다.

<figure class="third">
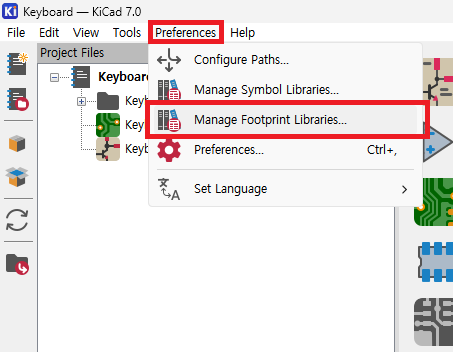
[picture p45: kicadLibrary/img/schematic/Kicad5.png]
    
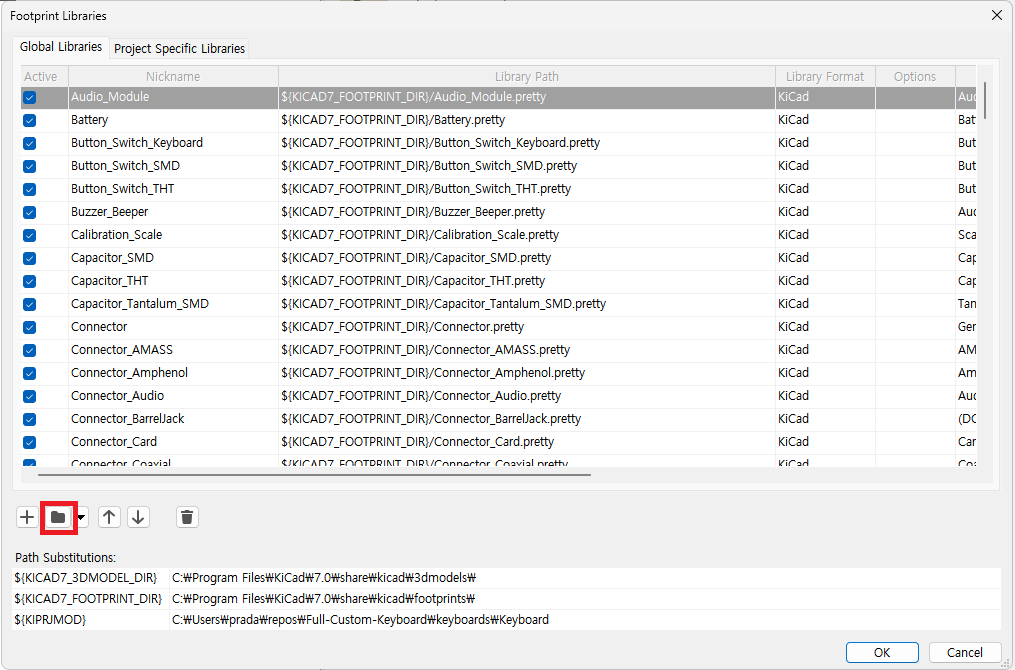
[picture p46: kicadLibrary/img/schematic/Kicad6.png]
    
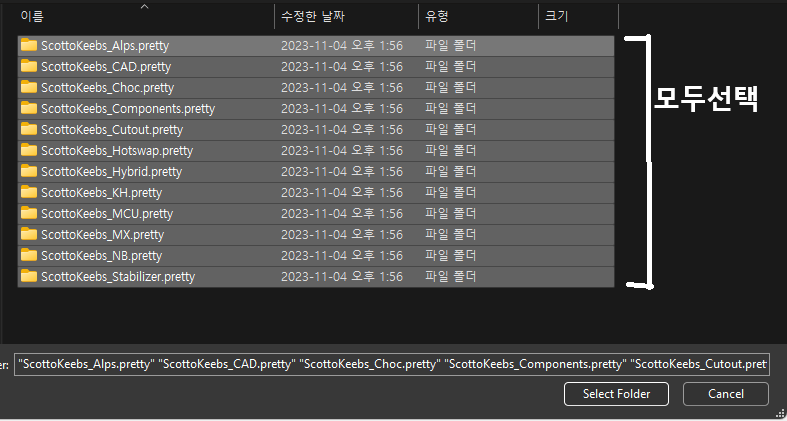
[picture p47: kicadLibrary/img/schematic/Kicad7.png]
      
</figure>

##### `Preferences > Manage Footprint Libraries` 로 들어가서 압축을 푼 파일의 Footprint 폴더 안에 있는 모든 폴더를 선택해줍니다.

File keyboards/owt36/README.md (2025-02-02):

# OWT36

3x5_3 unibody keyboard

+ wireless support
+ MX switch only

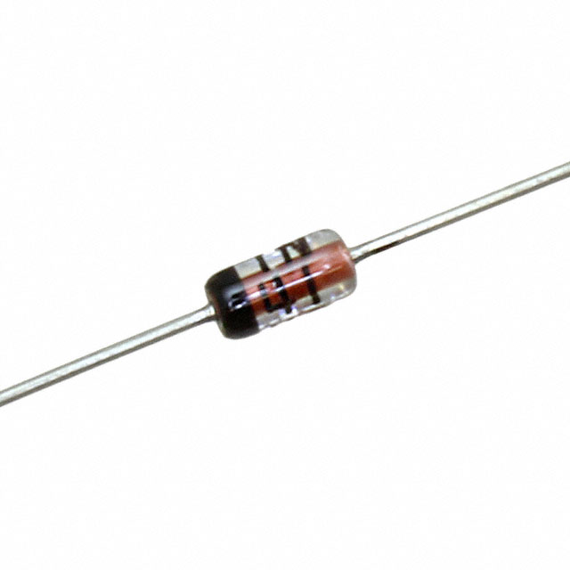
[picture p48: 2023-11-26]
img/schematic/schematic2.jpg

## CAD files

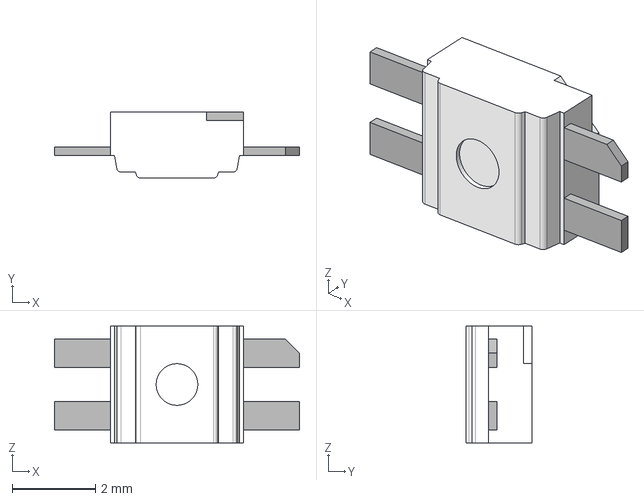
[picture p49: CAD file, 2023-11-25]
kicadLibrary/Keebio-Parts.pretty-master/3dmodels/SK6812MINI-E v1.step
5.88 x 1.58 x 2.80 mm

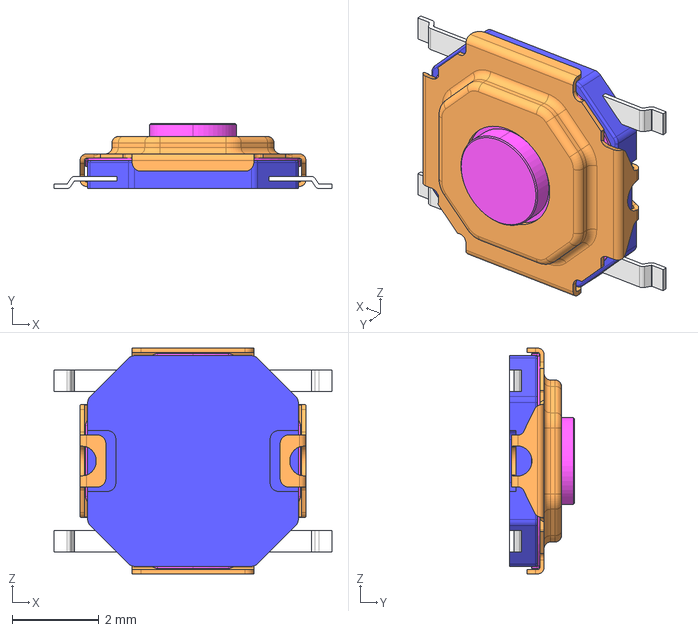
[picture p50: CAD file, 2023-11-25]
kicadLibrary/SKQGAFE010/SKQGAFE010.step
6.40 x 1.50 x 5.20 mm

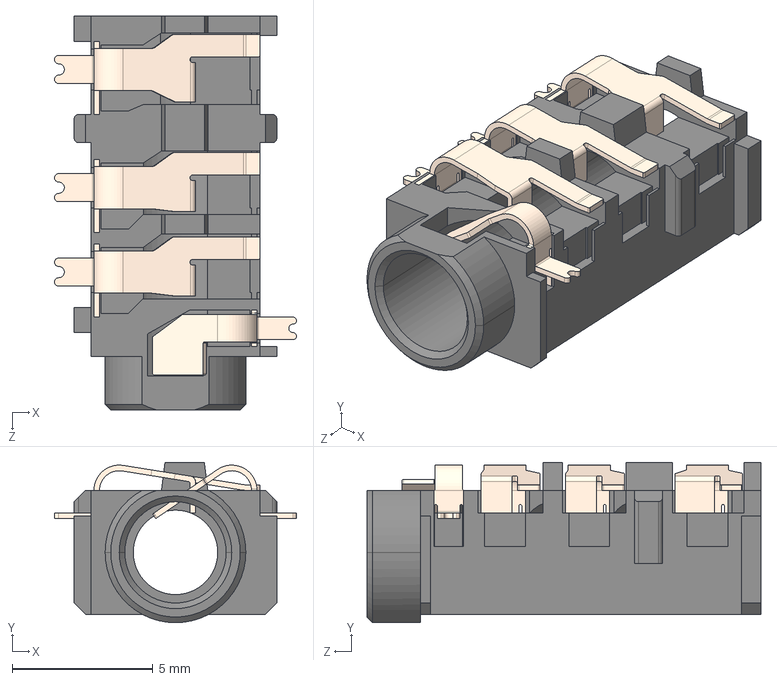
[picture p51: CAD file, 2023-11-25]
kicadLibrary/Keebio-Parts.pretty-master/3dmodels/CUI_SJ-43614-SMT-TR.step
8.60 x 5.70 x 14.0 mm

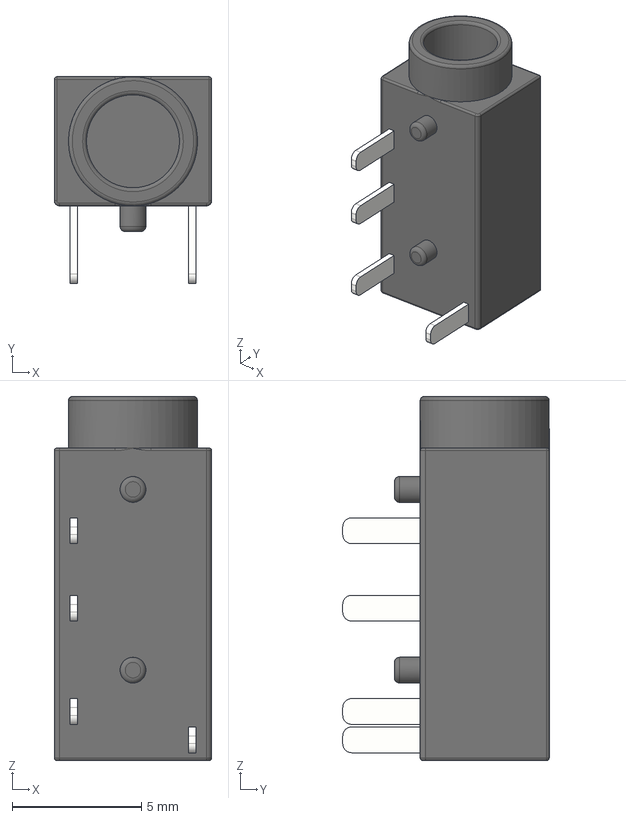
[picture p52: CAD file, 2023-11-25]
kicadLibrary/Keebio-Parts.pretty-master/3dmodels/PJ-320A.step
6.10 x 8.00 x 14.1 mm

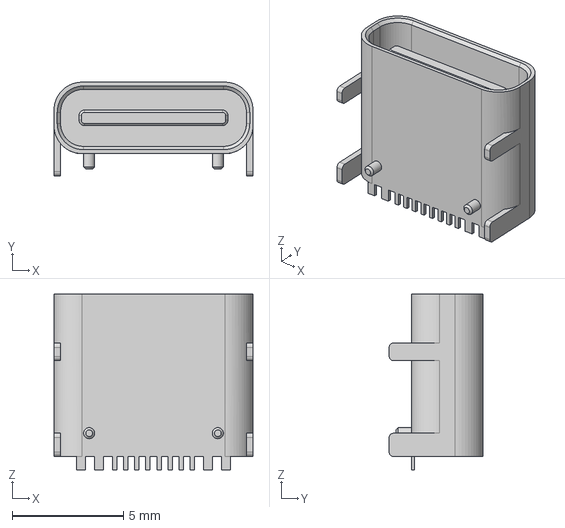
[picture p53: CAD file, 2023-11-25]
kicadLibrary/Keebio-Parts.pretty-master/3dmodels/HRO TYPE-C-31-M-12.step
8.94 x 4.21 x 7.90 mm

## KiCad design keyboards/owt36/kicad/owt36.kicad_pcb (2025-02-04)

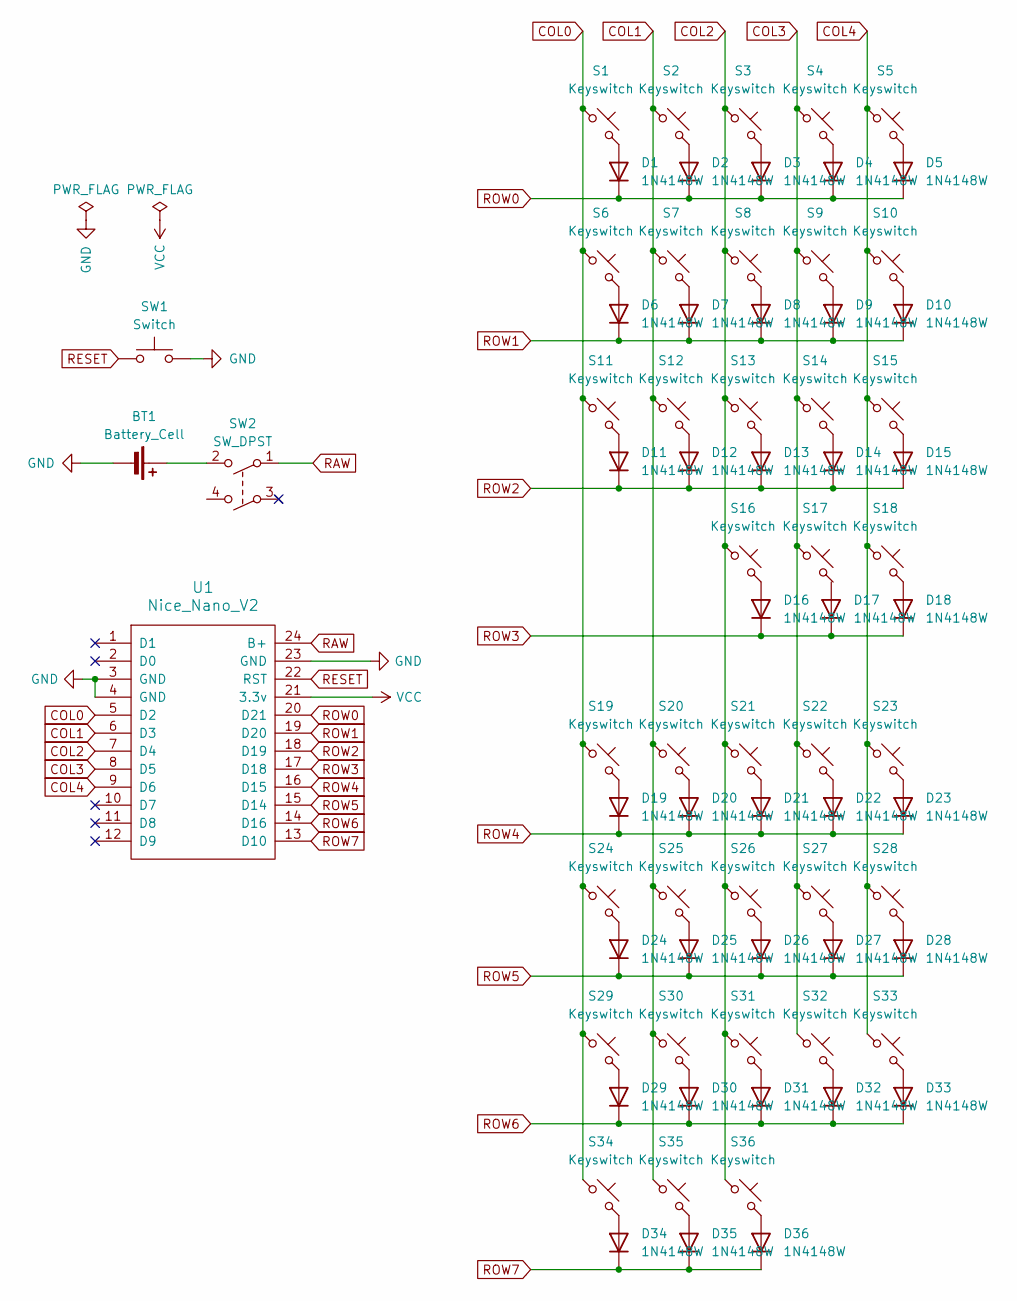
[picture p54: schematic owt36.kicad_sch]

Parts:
BT1: Battery_Cell; PinHeader_1x02_P2.00mm_Vertical
D1, D2, D3, D4, D5, D6, D7, D8, D9, D10, D11, D12, D13, D14, D15, D16, D17, D18, D19, D20, D21, D22, D23, D24, D25, D26, D27, D28, D29, D30, D31, D32, D33, D34, D35, D36: 1N4148W; Diode-Hybrid-Back
S1, S2, S3, S4, S5, S6, S7, S8, S9, S10, S11, S12, S13, S14, S15, S16, S17, S18, S19, S20, S21, S22, S23, S24, S25, S26, S27, S28, S29, S30, S31, S32, S33, S34, S35, S36: Keyswitch; Hotswap_MX_1.00u
SW1: Switch; SW_SPST_TL3342
SW2: SW_DPST; SW_SPDT_PCM12
U1: Nice_Nano_V2

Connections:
COL0: S1.1, S6.1, S11.1, S19.1, S24.1, S29.1, S34.1, U1.5 (D2)
COL1: S2.1, S7.1, S12.1, S20.1, S25.1, S30.1, S35.1, U1.6 (D3)
COL2: S3.1, S8.1, S13.1, S16.1, S21.1, S26.1, S31.1, S36.1, U1.7 (D4)
COL3: S4.1, S9.1, S14.1, S17.1, S22.1, S27.1, S32.1, U1.8 (D5)
COL4: S5.1, S10.1, S15.1, S18.1, S23.1, S28.1, S33.1, U1.9 (D6)
GND: BT1.2 (-), SW1.2, U1.3 (GND), U1.4 (GND), U1.23 (GND)
unnamed: BT1.1 (+), SW2.2
unnamed: D1.2 (A), S1.2
unnamed: D2.2 (A), S2.2
unnamed: D3.2 (A), S3.2
unnamed: D4.2 (A), S4.2
unnamed: D5.2 (A), S5.2
unnamed: D6.2 (A), S6.2
unnamed: D7.2 (A), S7.2
unnamed: D8.2 (A), S8.2
unnamed: D9.2 (A), S9.2
unnamed: D10.2 (A), S10.2
unnamed: D11.2 (A), S11.2
unnamed: D12.2 (A), S12.2
unnamed: D13.2 (A), S13.2
unnamed: D14.2 (A), S14.2
unnamed: D15.2 (A), S15.2
unnamed: D16.2 (A), S16.2
unnamed: D18.2 (A), S18.2
unnamed: D19.2 (A), S19.2
unnamed: D20.2 (A), S20.2
unnamed: D21.2 (A), S21.2
unnamed: D22.2 (A), S22.2
unnamed: D23.2 (A), S23.2
unnamed: D24.2 (A), S24.2
unnamed: D25.2 (A), S25.2
unnamed: D26.2 (A), S26.2
unnamed: D27.2 (A), S27.2
unnamed: D28.2 (A), S28.2
unnamed: D29.2 (A), S29.2
unnamed: D30.2 (A), S30.2
unnamed: D31.2 (A), S31.2
unnamed: D32.2 (A), S32.2
unnamed: D33.2 (A), S33.2
unnamed: D34.2 (A), S34.2
unnamed: D35.2 (A), S35.2
unnamed: D36.2 (A), S36.2
RAW: SW2.1, U1.24 (B+)
RESET: SW1.1, U1.22 (RST)
ROW0: D1.1 (K), D2.1 (K), D3.1 (K), D4.1 (K), D5.1 (K), U1.20 (D21)
ROW1: D6.1 (K), D7.1 (K), D8.1 (K), D9.1 (K), D10.1 (K), U1.19 (D20)
ROW2: D11.1 (K), D12.1 (K), D13.1 (K), D14.1 (K), D15.1 (K), U1.18 (D19)
ROW3: D16.1 (K), D17.1 (K), D18.1 (K), U1.17 (D18)
ROW4: D19.1 (K), D20.1 (K), D21.1 (K), D22.1 (K), D23.1 (K), U1.16 (D15)
ROW5: D24.1 (K), D25.1 (K), D26.1 (K), D27.1 (K), D28.1 (K), U1.15 (D14)
ROW6: D29.1 (K), D30.1 (K), D31.1 (K), D32.1 (K), D33.1 (K), U1.14 (D16)
ROW7: D34.1 (K), D35.1 (K), D36.1 (K), U1.13 (D10)
VCC: U1.21 (3.3v)

Board: 2 copper layers, 76 parts (3 on the bottom side), 52 nets, no tracks yet.

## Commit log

2023-11-25 제작한 키보드 업로드
    [scene46-B_Cu.gbr, scene46-B_Mask.gbr, scene46-B_Paste.gbr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]
2023-11-25 kiCad 라이브러리 업로드
    [CUI_SJ-43614-SMT-TR.step, HRO TYPE-C-31-M-12.step, PJ-320A.step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]
2023-11-26 add Kicad Scematic img
2023-11-26 edit footprintSymbol img
2023-11-26 Created New Project
    [Keyboard.kicad_pcb, Keyboard.kicad_sch]
2023-11-26 Add Howt to install kicad libraries
2023-11-26 Add kicad library img
2023-11-26 add schematic design guide
2023-11-26 add img for schematic design guide
2023-11-28 add TRRS Connection
    [Keyboard.kicad_sch]
2023-11-28 add img for footprint assignment
2023-11-28 add img for pcb design guide
2023-11-28 add pcb design guide
2023-11-28 complete schematic design and edit pcb file
    [Keyboard.kicad_pcb, Keyboard.kicad_sch]
2023-11-29 add PCB routing, Mounting Hole
    [Keyboard.kicad_pcb, Keyboard.kicad_sch]
2023-11-29 add pcb Edge.cuts, Design Rules Checker, and add filled zone
2023-11-29 keyboard pcb design complete
    [Keyboard.kicad_pcb, Keyboard.kicad_sch]
2023-12-05 add switch spec
2023-12-05 comlete pcb editing
    [Keyboard.kicad_pcb]
2023-12-05 add gerber (.gbr) files
    [Keyboard-B_Cu.gbl, Keyboard-B_Mask.gbs, Keyboard-B_Paste.gbp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]
2023-12-05 edit pcb file
    [Keyboard.kicad_pcb, Keyboard.kicad_sch]
2023-12-05 add plate imgs
2023-12-05 add plate design
2023-12-05 pcb edit final
2023-12-06 add new keyboard project
    [sceneBall48.kicad_pcb, sceneBall48.kicad_sch]
2023-12-10 scene ortho
    [sceneOrtho.kicad_pcb, sceneOrtho.kicad_sch]
2023-12-24 new keyboard using rasberry pi pico board
    [scenePiPico.kicad_pcb, scenePiPico.kicad_sch]
2025-02-01 add owt36 schematic
    [owt36.kicad_pcb, owt36.kicad_sch]
2025-02-04 owt36 pcb layout
    [owt36.kicad_pcb, owt36.kicad_sch]
